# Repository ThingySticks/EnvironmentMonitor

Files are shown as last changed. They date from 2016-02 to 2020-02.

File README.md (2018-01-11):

# Environment Monitor ThingySticks

Particle Photon or Electron based board to measure Humidity, Temperature, Light level and pressure.

* Compaible with Particle Power Shield to allow completly wireless monitoring.
* Compaible with Particle Asset Sheild to allow location information to be included with sensor data.
* Works with Photon or Electron.

## V2:

* Temperature, Humidity (HTU21D)
* Pressure (BMP180)
* Light (TEMT6000)
* Uses a Particle Photon or Electron
* Can piggyback onto Particle Asset Tracker and other ThingySticks prototype PCBs

Available on Tindie: https://www.tindie.com/products/ThingySticks/environment-sensor-for-the-photon-or-electron/

## V3:

Uses a BME680 - These are currently very hard (i.e. impossible) to get hold of. They were expected to be sold over a year ago, hence V3 of the monitor is on-hold.

## V4:

* Total Volatile Organic Compounds (TVOC) (CCS811)
* Equivelant CO2 (CCS811)
* Temperature, Humidity and Pressure (BME280)
* Light (TEMT6000)
* Uses a Particle Photon or Electron
* Can piggyback onto Particle Asset Tracker and other ThingySticks prototype PCBs

Available on Tindie: https://www.tindie.com/products/ThingySticks/air-quality-sensor-bme280ccs811-thingystick/

Build Files
-----------

Files used by the CI server to automate Eagle as part of a build process.

Clean.bat - As it says, pre build clean.
Build.bat - The build tasks (Generate images of the schematic, PCB top, bottom, all and measurements layers).
Distribute.bat - Copy the images to the appropriate places (S3....)

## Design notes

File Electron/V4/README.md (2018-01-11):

# Air Quality Thingy Stick

An air quality ThingyStick for the Particle Photon and Electron.

## Measures:

* Total Volatile Organic Compounds (TVOC) (CCS811)
* Equivelant CO2 (CCS811)
* Temperature, Humidity and Pressure (BME280)
* Light (TEMT6000)

## Buy

Available on Tindie: https://www.tindie.com/products/ThingySticks/air-quality-sensor-bme280ccs811-thingystick/

## Docs

http://thingysticks.com/Environment/V4/

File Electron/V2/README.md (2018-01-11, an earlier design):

# Environment Sensor ThingyStick

An environment sensor ThingyStick for the Particle Photon and Electron.

## Measures:

* Temperature, Humidity (HTU21D)
* Pressure (BMP180)
* Light (TEMT6000)

## Buy

Available on Tindie: https://www.tindie.com/products/ThingySticks/environment-sensor-for-the-photon-or-electron/

## Docs

http://thingysticks.com/Environment/V2/

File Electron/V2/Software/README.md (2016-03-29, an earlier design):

When using the build.particle.io platform you will need to manually add the HTU21D and PowerShield libraries (and remove the duplicated #includes at the head of the file.

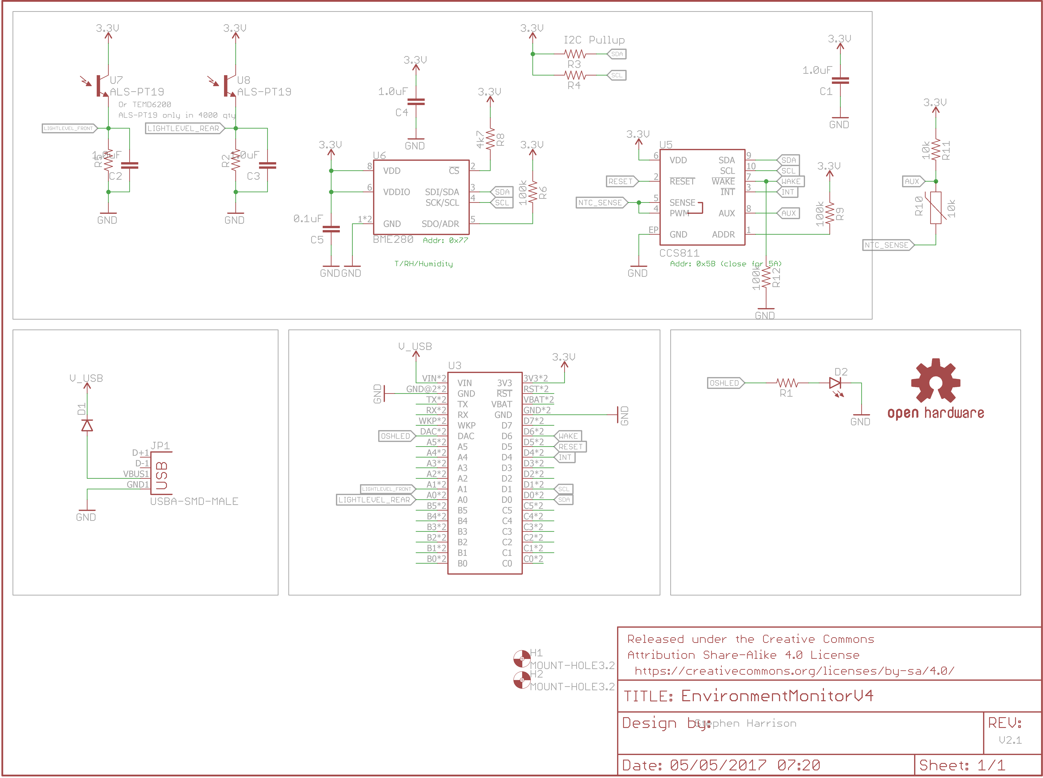
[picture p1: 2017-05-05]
Electron/V4/Images/Schematic.png

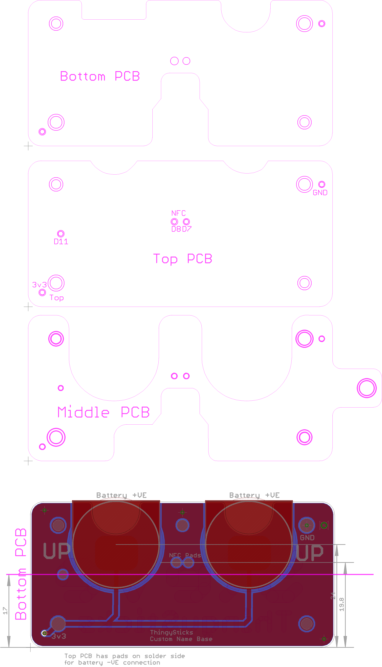
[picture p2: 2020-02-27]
ArduinoNano33/V10/BottomCustom/Images/V10.1/PcbAllLayersDesign.png

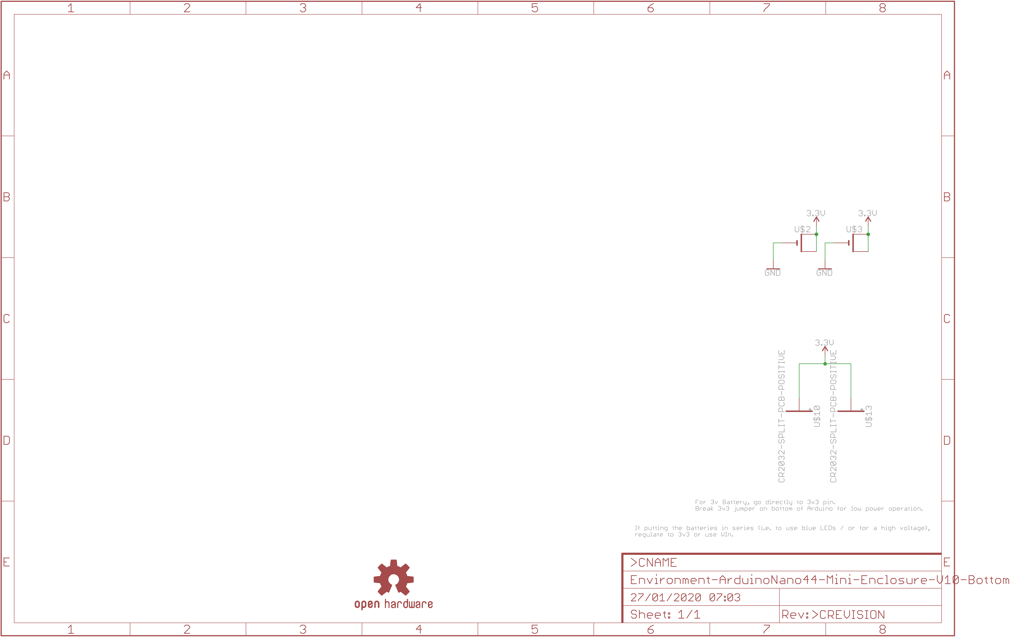
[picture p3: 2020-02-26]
ArduinoNano33/V10/BottomBasic/Images/V10/Schematic.png

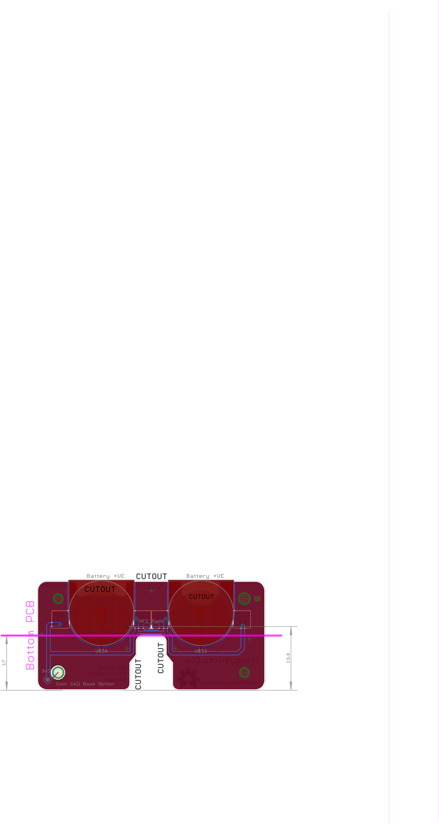
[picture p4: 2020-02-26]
ArduinoNano33/V10/BottomBasic/Images/V10/PcbAllLayersDesign.png

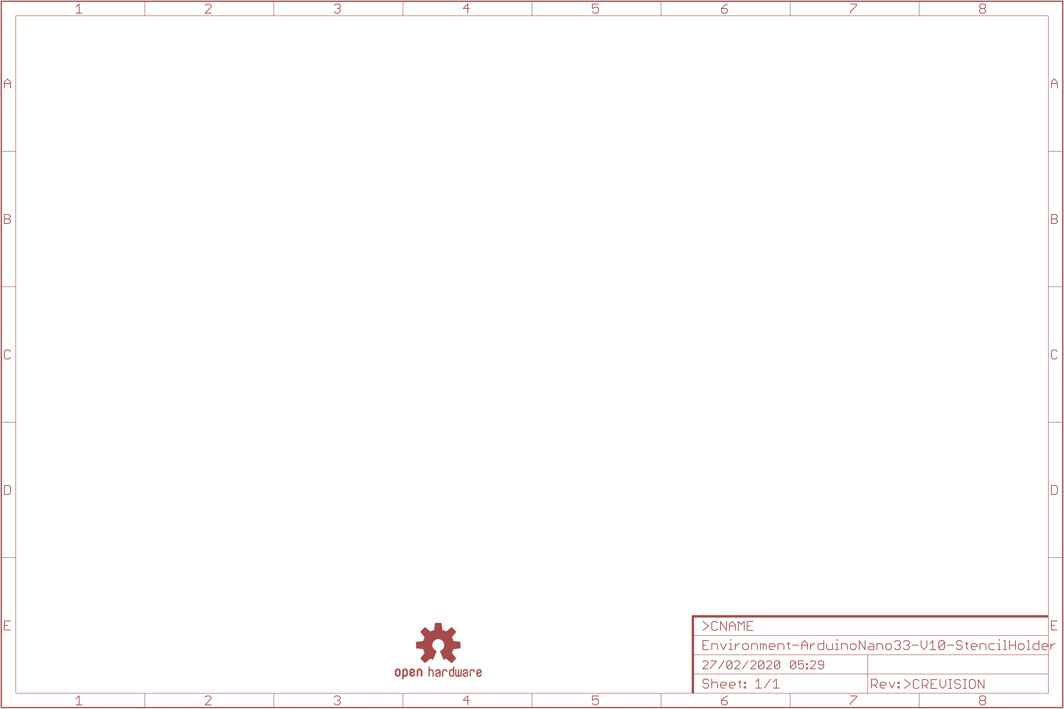
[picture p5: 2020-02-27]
ArduinoNano33/V10/StencilHolder/Images/Schematic.png

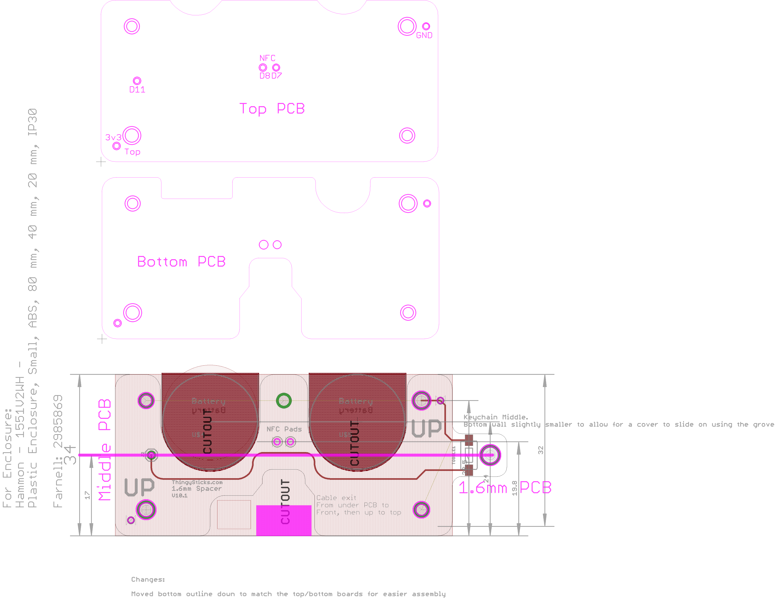
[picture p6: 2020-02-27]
ArduinoNano33/V10/MiddleWithRing/Images/V10.1/PcbAllLayersDesign.png

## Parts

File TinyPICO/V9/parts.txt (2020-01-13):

Partlist

Exported from Environment-TinyPICO-Mini-Enclosure-V9.brd at 12/01/2020 23:53

EAGLE Version 7.4.0 Copyright (c) 1988-2015 CadSoft

Assembly variant: 

Part     Value                      Package                    Library            Position (inch)       Orientation

BT2                                 BATTCON_12MM_PTH           ThingySticks       (2.06161417 0.33622047) R180
BT3                                 BATTCON_12MM_PTH           ThingySticks       (2.04911417 0.99517717) R0
C1       0.1uF                      0805                       ThingySticks       (0.425 0.1375)        R270
C2       1.0uF                      0805                       ThingySticks       (0.5125 0.1375)       R270
D1       Red                        LED-1206                   ThingySticks       (1.0625 1.2625)       R0
D2       Yellow                     LED-1206                   ThingySticks       (0.7875 1.2625)       R0
D3       Green                      LED-1206                   ThingySticks       (0.5125 1.2625)       R0
IC1      BME680                     BME680                     ThingySticks       (0.68897638 0.13061024) R90
J1                                  JST-2-SMD                  ThingySticks       (2.51968504 0.66929134) R90
JP1      JUMPER-SMT_2_NC_PASTE_SILK SMT-JUMPER_2_NC_PASTE_SILK SparkFun-Jumpers   (0.46318898 0.75875984) MR270
JP2      USB-NEW-MICROB             USB-MICROB                 Tinamous           (1.3976378 0.11811024) R0
R1       10k                        0805                       SparkFun-Resistors (0.85 0.2125)         R90
R2       4k7                        0805                       SparkFun-Resistors (1 0.55)              R90
R3       4k7                        0805                       SparkFun-Resistors (0.9 0.55)            R90
R4       1k5                        0805                       SparkFun-Resistors (0.4875 1.1625)       R0
R5       1k5                        0805                       SparkFun-Resistors (0.7625 1.1625)       R0
R6       1k5                        0805                       SparkFun-Resistors (0.9625 1.1625)       R180
U$2      TINY_PICO                  TINY_PICO                  ThingySticks       (0 1.0125)            R270

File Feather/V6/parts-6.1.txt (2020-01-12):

Partlist

Exported from EnvironmentMonitorV6.1.brd at 15/02/2019 21:37

EAGLE Version 7.4.0 Copyright (c) 1988-2015 CadSoft

Assembly variant: 

Part     Value                          Package                     Library                Position (mm)         Orientation

BT2                                     BATTERY_CR2-HOLDER-NO-HOLES ThingySticks           (15.6464 39.1668)     MR270
C1       1.0uF                          0805-CAP                    SparkFun-Capacitors    (49.6225 14.2425)     R180
C2       0.1uF                          0805-CAP                    SparkFun-Capacitors    (49.39 5.4)           R0
C3       1.0uF                          0805-CAP                    SparkFun-Capacitors    (46.0788 6.2206)      R270
C4       0.1uF                          0805-CAP                    SparkFun-Capacitors    (42.575 5.75)         R0
C5       1.0uF                          0805-CAP                    SparkFun-Capacitors    (64.2275 12.3375)     R180
C6       1.0uF                          0805-CAP                    SparkFun-Capacitors    (29.685 56.6175)      R180
C7       0.1uF                          0805-CAP                    SparkFun-Capacitors    (30.32 53.76)         R180
C8       0.1uF                          0805-CAP                    SparkFun-Capacitors    (15.875 62.865)       R270
C9       0.1uF                          0805-CAP                    SparkFun-Capacitors    (12.065 51.435)       R90
C10      10uF                           0805-CAP                    SparkFun-Capacitors    (13.335 62.865)       R90
C11      1.0uF                          0805-CAP                    SparkFun-Capacitors    (21.3 16.93)          R270
C12      2.2uF                          0805-CAP                    SparkFun-Capacitors    (18.7 17.03)          R270
C13      10uF                           0805-CAP                    SparkFun-Capacitors    (14.7 19.665)         R0
C14      0.1uF                          0805-CAP                    SparkFun-Capacitors    (14.7 16.465)         R0
C15      0.1uF                          0805-CAP                    SparkFun-Capacitors    (53.9496 23.4696)     R270
C16      10uF                           0805-CAP                    SparkFun-Capacitors    (51.997 23.5188)      R270
C17      0.1uF                          0805-CAP                    SparkFun-Capacitors    (10.16 60.96)         R180
C19      68uF                           EIA3528                     SparkFun-Capacitors    (8.5725 19.05)        R90
D1       IR                             LED-1206                    SparkFun-LED           (0.889 9.3726)        R270
D2                                      LED-1206-BOTTOM             SparkFun-LED           (43.815 66.04)        R180
D3       IR                             LED-1206                    SparkFun-LED           (3.77 9.365)          R270
D4                                      LED-1206                    ThingySticks           (33.9806 34.0044)     R180
D7       3A/10V/280mV                   SOD-323                     SparkFun-DiscreteSemi  (11.3538 36.9316)     R180
F1       6V/0.75A                       1206                        SparkFun-Fuses         (36.2712 36.8935)     R180
IC1      BME680                         BME680                      ThingySticks           (49.885 9.23)         R180
IC2      TCS3472                        FN-6                        TCS3472                (42.665 9.335)        R180
IC3      CCS811                         LGA10                       ThingySticks           (60 9.3)              R90
IC4                                     SPW2430HR5H-B               microbuilder           (13.97 58.42)         R0
IC5      FEATHERWINGPADS_AND_PLACE_ONLY FEATHERWIND_PADS_AND_PLACE  ThingySticks           (18.415 62.23)        MR180
J1                                      JST-2-SMD                   ThingySticks           (22.03 34.2225)       MR90
JP1      Charge Enable                  SMT-JUMPER_2_NC_PASTE_SILK  SparkFun-Jumpers       (11.3538 34.2646)     R180
JP2      Analog                         JST-4-PH-GROVE              ThingySticks           (26.035 67.945)       MR0
JP3      Serial                         JST-4-PH-GROVE              ThingySticks           (57.815 67.99)        MR0
JP6      I2C                            JST-4-PH-GROVE              ThingySticks           (60.325 33.02)        MR0
Q1       IRFML8244TRPBF                 SOT23-3                     SparkFun-DiscreteSemi  (4.3 4.715)           R0
Q2       4.3A/20V/54m?                  SOT23-3                     SparkFun-DiscreteSemi  (14.605 23.8125)      R270
R1       1k5                            0805                        SparkFun-Resistors     (50.295 66.03)        R0
R2       1K                             0805                        SparkFun-Resistors     (10.0584 63.8556)     R0
R3       4k7                            0805                        SparkFun-Resistors     (29.7365 20.0624)     R180
R4       4k7                            0805                        SparkFun-Resistors     (27.7553 17.9034)     R180
R5       10k                            0805                        SparkFun-Resistors     (47.625 48.895)       R90
R6       1M                             0805                        SparkFun-Resistors     (0.635 58.42)         R90
R7       10k                            0805                        SparkFun-Resistors     (8.89 51.435)         R90
R8       10k                            0805                        SparkFun-Resistors     (57.7342 29.9974)     R180
R9       10k                            0805                        SparkFun-Resistors     (57.785 46.99)        R90
R10      10k                            0805                        SparkFun-Resistors     (55.245 48.895)       R90
R11      4k7                            0805                        SparkFun-Resistors     (56.56 4.22)          R180
R12      10k                            0805                        SparkFun-Resistors     (5.715 51.435)        R270
R13      100R                           0805                        SparkFun-Resistors     (10.795 29.21)        R0
R14      20R                            0805                        SparkFun-Resistors     (21.3 22.1)           R90
R15      100R                           0805                        SparkFun-Resistors     (0.87 15.065)         R90
R16      1K                             0805                        SparkFun-Resistors     (39.5478 34.0298)     R0
R17      100R                           0805                        SparkFun-Resistors     (3.77 15.065)         R90
R18      10R                            0805                        SparkFun-Resistors     (-0.83 4.595)         R90
R19      1M                             0805                        SparkFun-Resistors     (4.2648 1.3122)       R0
R20      10k                            0805                        SparkFun-Resistors     (5.715 47.625)        R270
R21      10k                            0805                        SparkFun-Resistors     (52.705 45.085)       R90
R22      10k                            0805                        SparkFun-Resistors     (50.165 45.085)       R90
R23      1M                             0805                        SparkFun-Resistors     (14.605 29.21)        R180
U1       GRIDEYE                        GRIDEYE-AMG88               SparkFun-Sensors       (20 9.4126)           R0
U2       LMV358                         SO08                        SparkFun-IC-Amplifiers (6.35 57.15)          R270
U3       LIS3DH                         LGA-16-3X3                  SparkFun-Sensors       (58.42 25.4)          R180

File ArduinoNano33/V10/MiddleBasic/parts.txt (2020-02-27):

Partlist

Exported from Environment-ArduinoNano33-V10.1-MiddleBasic.brd at 27/02/2020 23:39

EAGLE Version 7.4.0 Copyright (c) 1988-2015 CadSoft

Assembly variant: 

Part     Value          Package  Library             Position (mm)         Orientation

J2                      1X01     SparkFun-Connectors (7.6 17)              R0

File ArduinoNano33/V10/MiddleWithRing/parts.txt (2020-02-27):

Partlist

Exported from Environment-ArduinoNano-V10.1-Middle-KeyChain.brd at 27/02/2020 23:31

EAGLE Version 7.4.0 Copyright (c) 1988-2015 CadSoft

Assembly variant: 

Part     Value                               Package                      Library             Position (mm)         Orientation

J2                                           1X01                         SparkFun-Connectors (7.6 17)              R0
TOGGLE1  MOMENTARY-SWITCH-SPST-SMD-6.0X3.5MM TACTILE_SWITCH_SMD_6.0X3.5MM ThingySticks        (74.5 17)             R90

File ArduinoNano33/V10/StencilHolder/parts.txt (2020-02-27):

Partlist

Exported from Environment-ArduinoNano33-V10-StencilHolder.brd at 27/02/2020 23:18

EAGLE Version 7.4.0 Copyright (c) 1988-2015 CadSoft

Assembly variant: 

Part     Value          Package  Library  Position (mm)         Orientation

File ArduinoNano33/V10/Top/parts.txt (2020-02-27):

Partlist

Exported from Environment-ArduinoNano33-V10.1-Top.brd at 27/02/2020 07:29

EAGLE Version 7.4.0 Copyright (c) 1988-2015 CadSoft

Assembly variant: 

Part     Value                                             Package                        Library                        Position (mm)         Orientation

C1       0.1uF                                             0805                           ThingySticks                   (10.795 3.4925)       R270
C2       1.0uF                                             0805                           ThingySticks                   (13.0175 3.4925)      R270
D1       Red                                               LED-1206                       ThingySticks                   (66.5 32.5)           R0
D2       Green                                             LED-1206                       ThingySticks                   (5 32.5)              R180
D3       Yellow                                            LED-1206                       ThingySticks                   (35.5 32.5)           R0
D4       Blue                                              LED-1206                       ThingySticks                   (47.5 20)             R270
D5       Blue                                              LED-1206                       ThingySticks                   (47.5 14)             R90
D6       Blue                                              LED-1206                       ThingySticks                   (50.5 11)             R0
D7       Blue                                              LED-1206                       ThingySticks                   (53.5 14)             R90
D8       Blue                                              LED-1206                       ThingySticks                   (53.5 20)             R90
D9       Blue                                              LED-1206                       ThingySticks                   (50.5 23)             R0
D10      Blue                                              LED-1206                       ThingySticks                   (50.5 17)             R180
D11      Blue                                              LED-1206                       ThingySticks                   (67.8 9.3)            R315
D13      Blue                                              LED-1206                       ThingySticks                   (60 20)               R90
D14      Blue                                              LED-1206                       ThingySticks                   (60 14)               R270
D15      Blue                                              LED-1206                       ThingySticks                   (63 11)               R0
D16      Blue                                              LED-1206                       ThingySticks                   (66 14)               R90
D17      Blue                                              LED-1206                       ThingySticks                   (66 20)               R270
D18      Blue                                              LED-1206                       ThingySticks                   (63 23)               R180
D19      Blue                                              LED-1206                       ThingySticks                   (63 17)               R0
D20      Green                                             LED-1206                       ThingySticks                   (50.5 2)              R0
D21      Green                                             LED-1206                       ThingySticks                   (63 2)                R180
D22      Blue                                              LED-1206                       ThingySticks                   (57 11.5)             R270
D23      Green                                             LED-1206                       ThingySticks                   (57 2)                R180
IC1      BME680                                            BME680                         ThingySticks                   (17.5 3.3175)         R90
J1                                                         1X01                           SparkFun-Connectors            (36.9 19.8)           R270
J3                                                         1X01                           SparkFun-Connectors            (7.6 17)              R0
J4       QUIC                                              JST04_1MM_RA                   SparkFun-Connectors-2020-01-17 (24.5 5)              MR0
J6                                                         1X01                           SparkFun-Connectors            (34.1 19.8)           R270
JP1      USB-NEW-MICROB                                    USB-MICROB                     Tinamous                       (35.4 3)              MR0
Q1       5.8A/30V/35m?                                     SOT23-3                        SparkFun-DiscreteSemi          (50.5 7)              R0
Q2       5.8A/30V/35m?                                     SOT23-3                        SparkFun-DiscreteSemi          (59.5 7)              R0
R1       10k                                               0805                           SparkFun-Resistors             (21.59 4.7975)        R90
R2       1k5                                               0805                           SparkFun-Resistors             (2 5.5)               R270
R3       1k5                                               0805                           SparkFun-Resistors             (35 28.8175)          R180
R4       1k5                                               0805                           SparkFun-Resistors             (31 33)               R180
R5       1k5                                               0805                           SparkFun-Resistors             (10.5 32)             R270
R6       200k                                              0805                           SparkFun-Resistors             (27.25 2.25)          R90
R7       100k                                              0805                           SparkFun-Resistors             (29.9 2.95)           R0
R9       1k5                                               0805                           SparkFun-Resistors             (54.5 9)              R90
R10      1k5                                               0805                           SparkFun-Resistors             (47 9)                R90
R11      1k5                                               0805                           SparkFun-Resistors             (2 29)                R90
R12      1k5                                               0805                           SparkFun-Resistors             (28 29)               R270
R13      1k5                                               0805                           SparkFun-Resistors             (30.5 29)             R270
R14      1k5                                               0805                           SparkFun-Resistors             (62 32.5)             R180
U$1      ARDUINO_33_NANOARDUINO_NANO_33_BLE_SENSE_SMD_WIDE ARDUINO_NANO_33_SMD_WIDER_PADS ThingySticks                   (1.25 8.305)          R90
U$6                                                        CR2032-SMD                     ThingySticks                   (20 24)               MR0
U$8      CR2032-SPLIT-PCBCR2032-NEGATIVE                   CR2032-SMD-NEGATIVE-TERMINAL   ThingySticks                   (20 24)               MR0
U$9      CR2032-SPLIT-PCBCR2032-NEGATIVE                   CR2032-SMD-NEGATIVE-TERMINAL   ThingySticks                   (51 24)               MR0

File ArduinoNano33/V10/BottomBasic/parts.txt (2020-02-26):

Partlist

Exported from Environment-ArduinoNano44-Mini-Enclosure-V10-Bottom.brd at 26/02/2020 16:30

EAGLE Version 7.4.0 Copyright (c) 1988-2015 CadSoft

Assembly variant: 

Part     Value                     Package                      Library      Position (mm)         Orientation

U$2                                CR2032-SMD                   ThingySticks (20 59)               MR0
U$3                                CR2032-SMD                   ThingySticks (51 59)               MR0
U$10     CR2032-SPLIT-PCB-POSITIVE CR2032-SMD-POSITIVE-TERMINAL ThingySticks (20 61)               MR0
U$13     CR2032-SPLIT-PCB-POSITIVE CR2032-SMD-POSITIVE-TERMINAL ThingySticks (51 61)               MR0

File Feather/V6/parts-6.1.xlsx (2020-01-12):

Partl | ist
Expor | ted | from Envir | onmentMonitorV6.1.brd at 15/02/2019 21:37
EAGLE | Ver | sion 7.4.0 | Copyright (c) 1988-2015 CadSoft
 |  |  |  |  |  |  |  |  |  | Number to make | 20
Assem | bly | variant: |  |  |  |  |  |  |  | Cost of parts | 746.82
 |  |  |  |  |  |  |  | Cost / Unit (@25) | QTY | Total
Part |  | Value | Package | Library | Position (mm) | Orientation |  | 68.731 | 56 | 37.341
C1 |  | 1.0uF | 0805-CAP | SparkFun-Capacitors | (49.6225 14.2425) | R180 | MC0805F105Z160CT | 0.114 | 1 | 0.114
C2 |  | 0.1uF | 0805-CAP | SparkFun-Capacitors | (49.39 5.4) | R0 | MC0805B104K101CT | 0.0327 | 1 | 0.0327
C3 |  | 1.0uF | 0805-CAP | SparkFun-Capacitors | (46.0788 6.2206) | R270 | MC0805F105Z160CT | 0.114 | 1 | 0.114
C4 |  | 0.1uF | 0805-CAP | SparkFun-Capacitors | (42.575 5.75) | R0 | MC0805B104K101CT | 0.0327 | 1 | 0.0327
C5 |  | 1.0uF | 0805-CAP | SparkFun-Capacitors | (64.2275 12.3375) | R180 | MC0805F105Z160CT | 0.114 | 1 | 0.114
C6 |  | 1.0uF | 0805-CAP | SparkFun-Capacitors | (29.685 56.6175) | R180 | MC0805F105Z160CT | 0.114 | 1 | 0.114
C7 |  | 0.1uF | 0805-CAP | SparkFun-Capacitors | (30.32 53.76) | R180 | MC0805B104K101CT | 0.0327 | 1 | 0.0327
C8 |  | 0.1uF | 0805-CAP | SparkFun-Capacitors | (15.875 62.865) | R270 | MC0805B104K101CT | 0.0327 | 1 | 0.0327
C9 |  | 0.1uF | 0805-CAP | SparkFun-Capacitors | (12.065 51.435) | R90 | MC0805B104K101CT | 0.0327 | 1 | 0.0327
C10 |  | 10uF | 0805-CAP | SparkFun-Capacitors | (13.335 62.865) | R90 | MC0805F105Z160CT | 0.0631 | 1 | 0.0631
C11 |  | 1.0uF | 0805-CAP | SparkFun-Capacitors | (21.3 16.93) | R270 | MC0805F105Z160CT | 0.114 | 1 | 0.114
C12 |  | 2.2uF | 0805-CAP | SparkFun-Capacitors | (18.7 17.03) | R270 | MC0805B225K250CT | 0.226 | 1 | 0.226
C13 |  | 10uF | 0805-CAP | SparkFun-Capacitors | (14.7 19.665) | R0 | MC0805F105Z160CT | 0.0631 | 1 | 0.0631
C14 |  | 0.1uF | 0805-CAP | SparkFun-Capacitors | (14.7 16.465) | R0 | MC0805B104K101CT | 0.0327 | 1 | 0.0327
C15 |  | 0.1uF | 0805-CAP | SparkFun-Capacitors | (53.9496 23.4696) | R270 | MC0805B104K101CT | 0.0327 | 1 | 0.0327
C16 |  | 10uF | 0805-CAP | SparkFun-Capacitors | (51.997 23.5188) | R270 | MC0805F105Z160CT | 0.0631 | 1 | 0.0631
C17 |  | 0.1uF | 0805-CAP | SparkFun-Capacitors | (10.16 60.96) | R180 | MC0805B104K101CT | 0.0327 | 1 | 0.0327
C19 |  | 68uF | EIA3528 | SparkFun-Capacitors | (8.5725 19.05) | R90 | T499B336K006ATE3K0 | 0.741 | 1 | 0.741
D1 |  | IR | LED-1206 | SparkFun-LED | (0.889 9.3726) | R270 | OIS 330 770 | 1.24 | 1 | 1.24
D4 |  | Reverse LED | LED-1206 | ThingySticks | (33.9806 34.0044) | R180 | KPTL-3216QBC-D-01 | 0.2 | 1 | 0.2 |  | 0.247 | 25x 0.20 |  |  | 100x 0.184
F1 |  | 6V/0.75A | 1206 | SparkFun-Fuses | (36.2712 36.8935) | R180 | 1206L075THYR (https://uk.farnell.com/littelfuse/1206l075thyr/polyfuse-ptc-1206-0-75a/dp/1822204?st=1206%20LITTLE%20FUSE) | 0.3 | 1 | 0.3
IC1 |  | BME680 | BME680 | ThingySticks | (49.885 9.23) | R180 | BME680 | 8.22 | 1 | 8.22 |  | 1x 9.84 | 10x 8.22 | 25x 7.62 | 50x 7.41 | 100x 6.38 | 250x 6.17 | 2500x 4.94
IC2 |  | TCS3472 | FN-6 | TCS3472 | (42.665 9.335) | R180 | TCS34725FN | 1.96 | 1 | 1.96 |  | 1x 2.44 | 10x2.18 | 25x 1.96 | 50x 1.87 | 100x 1.78 | 250x 1.62 | 2000x 1.18 | 3500x 1.18
IC3 |  | CCS811 | LGA10 | ThingySticks | (60 9.3) | R90 | CCS811B-JOPD500 | 6.89 | 1 | 6.89 |  | 1x 8.62 | 10x 7.76 | 25x 6.89 | 6.37 | 5.51 | 5.16 | 1000x 4.39
IC4 |  |  | SPW2430HR5H-B | microbuilder | (13.97 58.42) | R0 | SPW2430HR5H-B | 0.441 | 1 | 0.441 |  | 0.656 | 0.52 | 0.441 | 0.401 | 0.377 | 0.352 | 0.241
J1 |  |  | JST-2-SMD | ThingySticks | (22.03 34.2225) | MR90 |  |  | 1 | 0
Q1 |  | IRFML8244T | RPBF SOT23-3 | SparkFun-DiscreteSem | i (4.3 4.715) | R0 | IRFML8244TRPBF | 0.212 | 1 | 0.212
Q2 |  | P-Channel | 4m? SOT23-3 | SparkFun-DiscreteSem | i (14.605 23.8125) | R270 |  | 0.212 | 1 | 0.212
R1 |  | 1k5 | 805 | SparkFun-Resistors | (50.295 66.03) | R0 | MCWR08X1501FTL | 0.0016 | 1 | 0.0016
R2 |  | 1K | 805 | SparkFun-Resistors | (10.0584 63.8556) | R0 | MCWR08X1001FTL | 0.0081 | 1 | 0.0081
R3 |  | 4k7 | 805 | SparkFun-Resistors | (29.7365 20.0624) | R180 | MCWR08X4701FTL | 0.0081 | 1 | 0.0081
R4 |  | 4k7 | 805 | SparkFun-Resistors | (27.7553 17.9034) | R180 | MCWR08X4701FTL | 0.0081 | 1 | 0.0081
R5 |  | 10k | 805 | SparkFun-Resistors | (47.625 48.895) | R90 | MCWR08X1002FTL | 0.0086 | 1 | 0.0086
R6 |  | 1M | 805 | SparkFun-Resistors | (0.635 58.42) | R90 | MCWR08X1004FTL | 0.0086 | 1 | 0.0086
R7 |  | 10k | 805 | SparkFun-Resistors | (8.89 51.435) | R90 | MCWR08X1002FTL | 0.0086 | 1 | 0.0086
R8 |  | 10k | 805 | SparkFun-Resistors | (57.7342 29.9974) | R180 | MCWR08X1002FTL | 0.0086 | 1 | 0.0086
R9 |  | 10k | 805 | SparkFun-Resistors | (57.785 46.99) | R90 | MCWR08X1002FTL | 0.0086 | 1 | 0.0086
R10 |  | 10k | 805 | SparkFun-Resistors | (55.245 48.895) | R90 | MCWR08X1002FTL | 0.0086 | 1 | 0.0086
R11 |  | 4k7 | 805 | SparkFun-Resistors | (56.56 4.22) | R180 | MCWR08X4701FTL | 0.0081 | 1 | 0.0081
R12 |  | 10k | 805 | SparkFun-Resistors | (5.715 51.435) | R270 | MCWR08X1002FTL | 0.0086 | 1 | 0.0086
R13 |  | 100R | 805 | SparkFun-Resistors | (10.795 29.21) | R0 | MCWR08X1000FTL | 0.0086 | 1 | 0.0086
R14 |  | 20R | 805 | SparkFun-Resistors | (21.3 22.1) | R90 | MCWR08X20R0FTL | 0.0084 | 1 | 0.0084
R15 |  | 100R | 805 | SparkFun-Resistors | (0.87 15.065) | R90 | MCWR08X1000FTL | 0.0086 | 1 | 0.0086
R16 |  | 1K | 805 | SparkFun-Resistors | (39.5478 34.0298) | R0 | MCWR08X1001FTL | 0.0081 | 1 | 0.0081
R17 |  | 100R | 805 | SparkFun-Resistors | (3.77 15.065) | R90 | MCWR08X1000FTL | 0.0086 | 1 | 0.0086
R18 |  | 10R | 805 | SparkFun-Resistors | (-0.83 4.595) | R90 | MCWR08X10R0FTL | 0.0016 | 1 | 0.0016
R19 |  | 1M | 805 | SparkFun-Resistors | (4.2648 1.3122) | R0 | MCWR08X1004FTL | 0.0086 | 1 | 0.0086
R20 |  | 10k | 805 | SparkFun-Resistors | (5.715 47.625) | R270 | MCWR08X1002FTL | 0.0086 | 1 | 0.0086
R21 |  | 10k | 805 | SparkFun-Resistors | (52.705 45.085) | R90 | MCWR08X1002FTL | 0.0086 | 1 | 0.0086
R22 |  | 10k | 805 | SparkFun-Resistors | (50.165 45.085) | R90 | MCWR08X1002FTL | 0.0086 | 1 | 0.0086
R23 |  | 1M | 805 | SparkFun-Resistors | (14.605 29.21) | R180 | MCWR08X1004FTL | 0.0086 | 1 | 0.0086
U1 |  | GRIDEYE | GRIDEYE-AMG88 | SparkFun-Sensors | (20 9.4126) | R0 | AMG8833 | 16.39 | 0 | 0 |  | 16.91 | 10x 16.39 | 50x 14.49 | 100x 13.32
U2 |  | LMV358 | SO08 | SparkFun-IC-Amplifie | rs (6.35 57.15) | R270 | LMV358ID | 0.486 | 1 | 0.486 |  | 0.556 | 50x 0.486 | 100x 0.313 | 250x 0.292 | 500x 2.72
U3 |  | LIS3DH | LGA-16-3X3 | SparkFun-Sensors | (58.42 25.4) | R180 | LIS3DHHTR | 0.961 | 1 | 0.961 |  | 1.12 | 10x 0.961 | 100x 0.738 | 500x 0.654
 |  | PCB Cost |  |  |  |  |  | 2 | 1 | 2
 |  | Assembly Cost |  |  |  |  |  | 9.35 | 1 | 9.35 |  | 1-49 $12.2 | 50-200 $5.4 | 200-500 $2.0
 |  | Enclosure |  |  |  |  |  | 2.7 | 1 | 2.7 |  | 2.76 | 25x 2.70 | 50x 2.65 | 250x 2.59
 |  | Xenon |  |  |  |  |  | 15 | 0 | 0
 |  |  |  |  |  |  |  |  |  |  |  | 2.65 | 250 | 662.5

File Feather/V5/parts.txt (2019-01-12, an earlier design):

Partlist exported from S:/github/ThingySticks/EnvironmentMonitor/Feather/V5/PCB/EnvironmentMonitorV5.sch at 12/01/2019 20:36

Part   Value             Device                   Package          Description                                                                                                                           CPC     PROD_ID     SEEEDSTUDIO VALUE         
C1     1.0uF             1.0UF-25V-+80/-20(0805)" 0805-CAP         CAP-11625                                                                                                                                     CAP-11625               1.0uF         
C2     0.1uF             1.0UF-25V-+80/-20(0805)" 0805-CAP         CAP-11625                                                                                                                                     CAP-11625               1.0uF         
C3     1.0uF             1.0UF-25V-+80/-20(0805)" 0805-CAP         CAP-11625                                                                                                                                     CAP-11625               1.0uF         
C4     0.1uF             1.0UF-25V-+80/-20(0805)" 0805-CAP         CAP-11625                                                                                                                                     CAP-11625               1.0uF         
D2                       LED1206-BOTTOM           LED-1206-BOTTOM  LEDs                                                                                                                                                                                
FRAME1 FRAME-LETTER      FRAME-LETTER             CREATIVE_COMMONS Schematic Frame                                                                                                                                                                     
H1     MOUNT-HOLE2.8     MOUNT-HOLE2.8            2,8              MOUNTING HOLE with drill center marker                                                                                                                                              
H2     MOUNT-HOLE2.8     MOUNT-HOLE2.8            2,8              MOUNTING HOLE with drill center marker                                                                                                                                              
H3     MOUNT-HOLE2.8     MOUNT-HOLE2.8            2,8              MOUNTING HOLE with drill center marker                                                                                                                                              
H4     MOUNT-HOLE2.8     MOUNT-HOLE2.8            2,8              MOUNTING HOLE with drill center marker                                                                                                                                              
IC1    BME680            BME680                   BME680           BME680 integrates for the first time individual high linearity and high accuracy sensors for gas, pressure, humidity and temperature.                                               
IC2    TCS3472           TCS3472                  FN-6                                                                                                                                                                                                 
JP1    A1-2              M04JST-PTH-VERT          JST-4-PTH-VERT   Header 4                                                                                                                              MK00368             110990030                 
JP2    A3-4              M04JST-PTH-VERT          JST-4-PTH-VERT   Header 4                                                                                                                                                                            
JP3    Serial            M04JST-PTH-VERT          JST-4-PTH-VERT   Header 4                                                                                                                                                                            
JP4    D7-8              M04JST-PTH-VERT          JST-4-PTH-VERT   Header 4                                                                                                                                                                            
JP5    I2C1 - D2-3       M04JST-PTH-VERT          JST-4-PTH-VERT   Header 4                                                                                                                                                                            
JP6    I2C               M04JST-PTH-VERT          JST-4-PTH-VERT   Header 4                                                                                                                                                                            
JP7    Ext. Power (5v)   M02POLAR_LOCK            MOLEX-1X2_LOCK   Standard 2-pin 0.1" header. Use with                                                                                                                                                
JP9    FAN               M03POLAR                 MOLEX-1X3        Header 3                                                                                                                                                                            
JP10   FAN Power in      M02POLAR_LOCK            MOLEX-1X2_LOCK   Standard 2-pin 0.1" header. Use with                                                                                                                                                
JP11                     M03PTH                   1X03             Header 3                                                                                                                                                                            
LOGO1  OSHW-LOGOM        OSHW-LOGOM               OSHW-LOGO-M      Open Source Hardware Logo                                                                                                                                                           
MS1    FEATHERWING_NODIM FEATHERWING_NODIM        FEATHERWING_DIM                                                                                                                                                                                      
Q1     220mA/50V/3.5O    MOSFET-NCH-BSS138        SOT23-3          N-channel MOSFETs                                                                                                                             TRANS-00830             220mA/50V/3.5O
Q2     4.3A/20V/54mO     MOSFET_PCH-IRLML2244     SOT23-3          P-channel MOSFETs                                                                                                                             TRANS-11153             4.3A/20V/54mO 
R1     310R              RESISTOR0805-RES         0805             Resistor                                                                                                                                                                            
R2     1M                RESISTOR0805-RES         0805             Resistor                                                                                                                                                                            
R3     4k7               RESISTOR0805-RES         0805             Resistor                                                                                                                                                                            
R4     4k7               RESISTOR0805-RES         0805             Resistor                                                                                                                                                                            
R5     10k               RESISTOR0805-RES         0805             Resistor                                                                                                                                                                            
R6     1M                RESISTOR0805-RES         0805             Resistor                                                                                                                                                                            
R7     10R               RESISTOR0805-RES         0805             Resistor

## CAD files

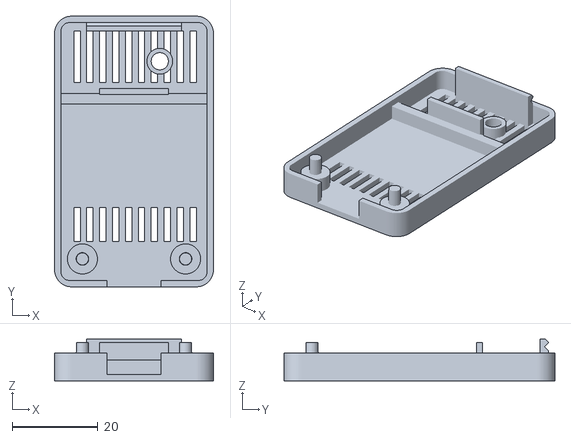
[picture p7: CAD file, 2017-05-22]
Photon/V4.1/Case/PhotonCase.stl
37.0 x 63.0 x 9.75

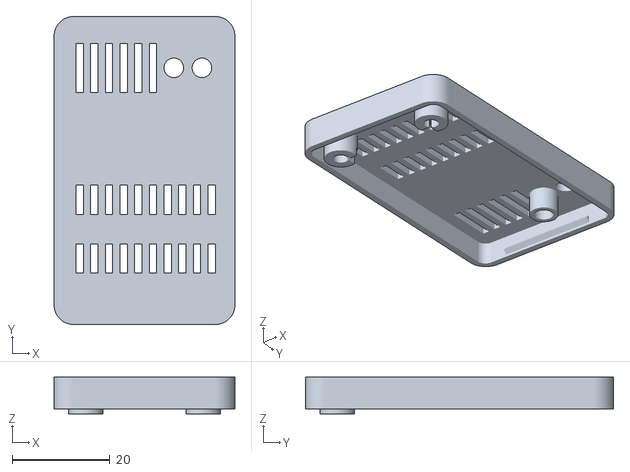
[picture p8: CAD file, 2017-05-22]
Photon/V4.1/Case/PhotonCase-Lid.stl
37.0 x 63.0 x 7.50

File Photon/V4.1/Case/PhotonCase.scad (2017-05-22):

$fn=60;

pcbLength = 55;
pcbWidth = 32;
pcbHeight = 0.8;

pcbXOffset = 2.5;
pcbYOffset = 2.5;
pcbZOffset = 5;

// ==========================================================
// Models
// ==========================================================

module showPcb() {
    roundedCube(pcbWidth, pcbLength, pcbHeight , 4);
    
    // Hole
    translate([4,4,-2]) {
        #cylinder(d=3, h=4);
    }
    
    // Hole
    translate([4+24,4,-2]) {
        cylinder(d=3, h=4);
    }
    
    // Thermal cutout
    translate([7.6,42.1,-2]) {
        cube([pcbWidth-(7.6 * 2),1.6,4]);
    }
    
    // USB
    translate([(pcbWidth-12)/2,-15,-3]) {
        cube([12,15,4.5]);
    }
    
    // Photon
    translate([5.7,5,pcbHeight]) {
        // Height the max of the PCB - USB plug + aerial
        cube([20,37,4]);
    }
    
    // JST for battery
    translate([6,17,-6]) {
        // Height the max of the PCB - USB plug + aerial
        cube([20,10,6]);
    }
    
    // LED
    translate([20,48,-1]) {
        // Height the max of the PCB - USB plug + aerial
        cube([11,5,1]);
    }
    
    translate([28,50,-1]) {
        // Height the max of the PCB - USB plug + aerial
        #cylinder(d=2, h=20);
    }
}

// ==========================================================
// Helpers
// ==========================================================

module roundedCube(width, height, depth, cornerDiameter) {
//cornerDiameter = 5;
cornerRadius = cornerDiameter/2;
    
    translate([cornerDiameter/2,0,0]) {
        cube([width-cornerDiameter, height, depth]);
    }
    
    translate([0,cornerDiameter/2,0]) {
        cube([width, height-cornerDiameter, depth]);
    }
    
    translate([cornerRadius,cornerRadius,0]) {
        cylinder(d=cornerDiameter, h=depth);
    }
    
    translate([width-cornerRadius,cornerRadius,0]) {
        cylinder(d=cornerDiameter, h=depth);
    }
    
    translate([cornerRadius,height-cornerRadius,0]) {
        cylinder(d=cornerDiameter, h=depth);
    }
    
    translate([width-cornerRadius,height-cornerRadius,0]) {
        cylinder(d=cornerDiameter, h=depth);
    }
}

// ==========================================================
// PCB Mounts
// ==========================================================

module pcbMountingPads() {
    translate([pcbXOffset, pcbYOffset,0]) {
        pcbMountingPin(4,4);
        pcbMountingPin(4+24,4);
    }
}

module pcbMountingPad(x,y) {
    translate([x,y,0]) {
        difference() {
            cylinder(d=7, h=pcbZOffset);
            cylinder(d=1, h=4);
        }
    }
}

module pcbMountingPin(x,y) {
    translate([x,y,0]) {
        cylinder(d=7, h=pcbZOffset);
        cylinder(d1=3.1, d2=2.8, h=pcbZOffset+4);
    }
}

// A Support "pad" for the back of the PCB.
// use the slot in the PCB to help stabalise things.
module pcbSupport() {
    translate([pcbXOffset, pcbYOffset,0]) {
        // Add a pad
        // 9mm from pCB edge.
        translate([-pcbXOffset,40,0]) {
            cube([pcbWidth + (pcbXOffset*2),2.5,pcbZOffset-0.1]);
        }
            
        // add a riser
        translate([8,42.25,0]) {
            cube([16,1.4,pcbZOffset+4]);
        }
    }
}

module pcbMountingReceptors() {
    translate([pcbXOffset, pcbYOffset,-1]) {
        pcbMountingReceptor(4,4);
        pcbMountingReceptor(4+24,4);
    }
}

module pcbMountingReceptor(x,y) {
    translate([x,y,0]) {
        difference() {
            cylinder(d=7, h=mainBodyHeight+1);
            cylinder(d=3.2, h=mainBodyHeight+1-2);
        }
    }
}

// ==========================================================

mainBodyHeight = 6.5;
    //mainBodyHeight = 1;

module usbCutout() {
usbWidth  = 12.5;
xPosition = (pcbWidth / 2) - (usbWidth / 2) + pcbXOffset;
    
    // USB plug pretrudes 3.3mm below the PCB 
    translate([xPosition, -0.1,pcbZOffset - 3.5]) {
        // Ensure no top is put onto the USB
       # cube([usbWidth,3,5.5]);
    }
}

module photodiodeTopHole(height) {
    translate([22, 50,0]) {
        difference() {
            union() {
                cylinder(d=6, h=height);
            }
            union() {
                cylinder(d=4, h=height);
            }
        }
    }
}


module body() {   
    
    difference() {
        union() {
            roundedCube(pcbWidth + pcbXOffset * 2, 63, mainBodyHeight, 8) ;
        }
        union() {
            translate([1.5,1.5,1.5]) {
                // 1mm difference between wall nand pcbXOffset
                // double that so it's either side.
                roundedCube(pcbWidth + 2, 60, mainBodyHeight, 4) ;
            }
            
            usbCutout();
            
            // Vent holes for sensors
            translate([pcbXOffset,pcbYOffset,-0.1]) {
                for (i = [2 : 3 : 30]) {
                    translate([i, 45,0]) {
                        #cube([1.5, 12,  2]);
                    }
                }
            }
            
            // Vent holes for Photon heat
            translate([pcbXOffset,pcbYOffset,-0.1]) {
                for (i = [2 : 3 : 30]) {
                    translate([i, 8,0]) {
                        // Shorter to allow for a cutout for the JST
                        #cube([1.5, 8,  2]);
                    }
                }
            }
            
            // Photodiode hole.
            translate([pcbXOffset,pcbYOffset,-0.1]) {
                translate([22, 50,0]) {
                    #cylinder(d=4, h=mainBodyHeight+1);
                }
            }
        }
    }
    
    pcbMountingPads();
    pcbSupport();
    
    translate([pcbXOffset,pcbYOffset,0]) {
        photodiodeTopHole(pcbZOffset-1);
    }
    
    // End catch to get the lid
    translate([7.5,63-3.5,0]) {
        difference() {
            union() {
                cube([pcbWidth-10,2, mainBodyHeight + mainBodyHeight/2]);
            }
            union() {
                translate([0,2.5,mainBodyHeight ]) {
                    rotate([45, 0,0]) {
                        cube([pcbWidth-10,2, 2]);
                    }
                }
                translate([0,2.5,mainBodyHeight+2 ]) {
                    rotate([45, 0,0]) {
                        cube([pcbWidth-10,2, 2]);
                    }
                }
            }
        }
    }
}


module lid() {
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

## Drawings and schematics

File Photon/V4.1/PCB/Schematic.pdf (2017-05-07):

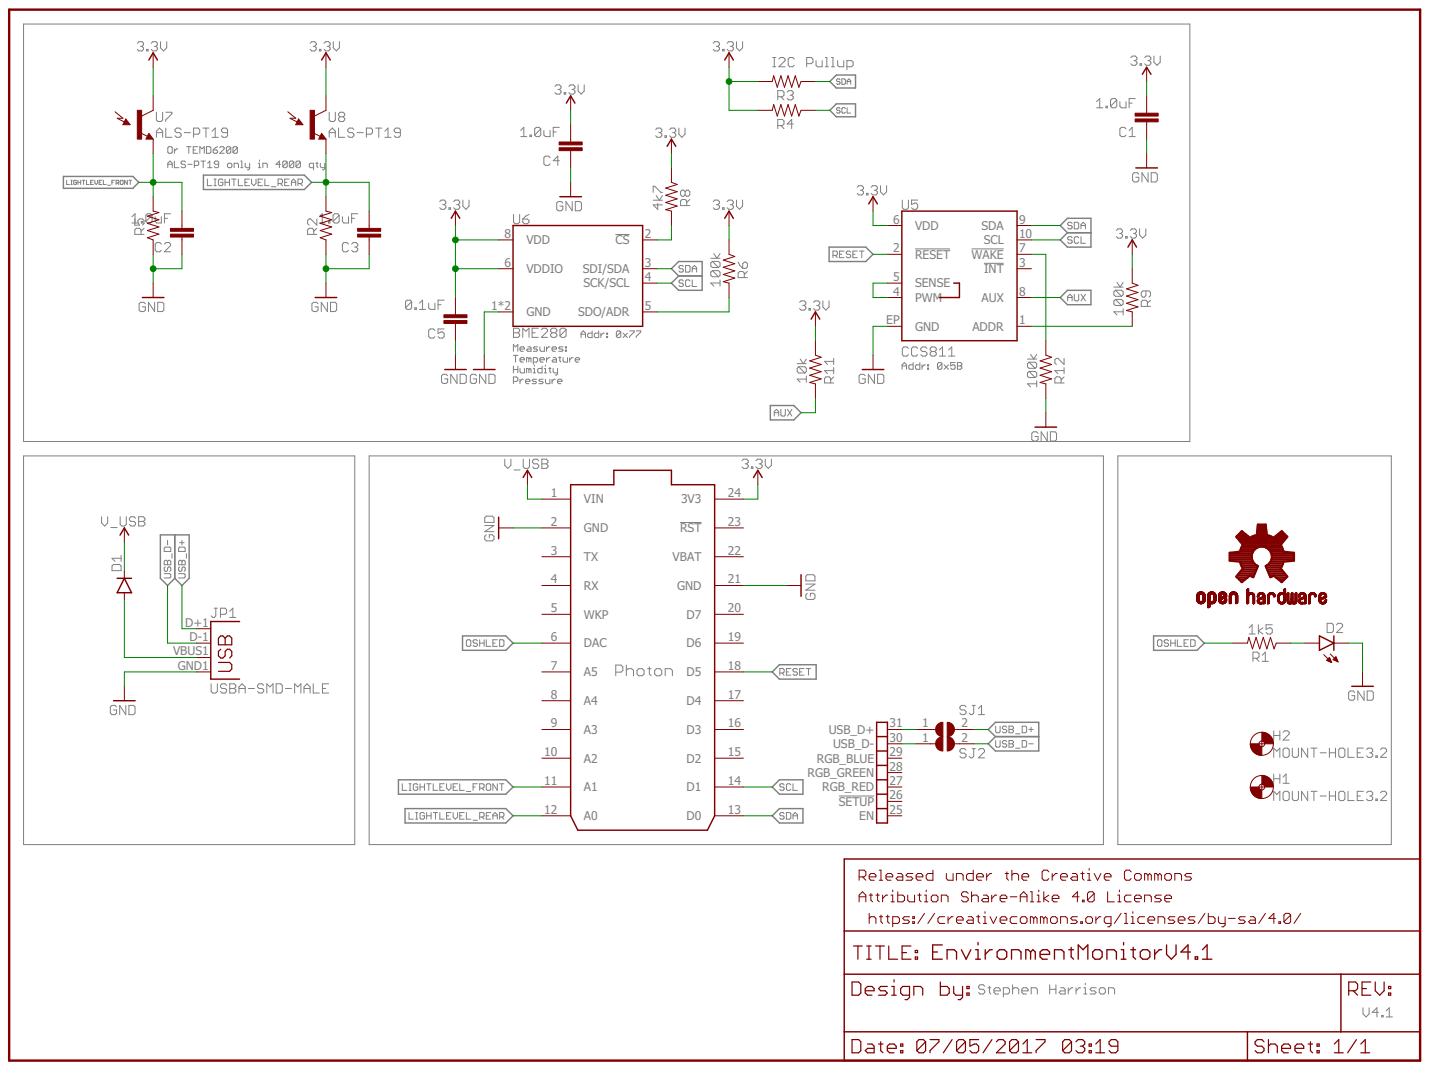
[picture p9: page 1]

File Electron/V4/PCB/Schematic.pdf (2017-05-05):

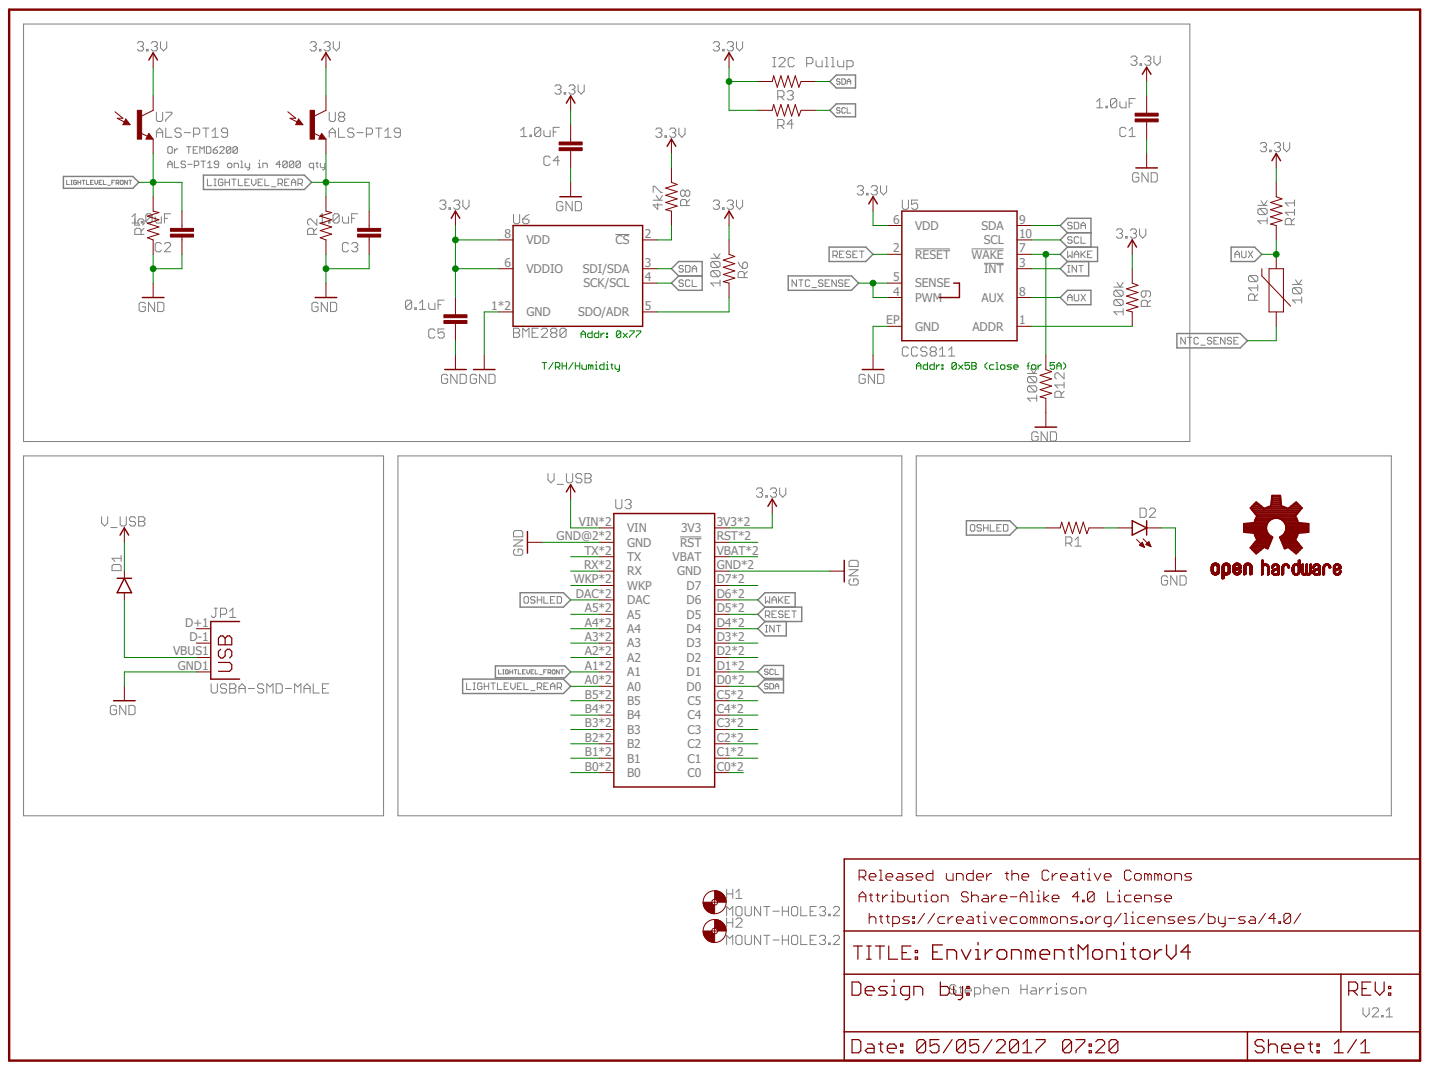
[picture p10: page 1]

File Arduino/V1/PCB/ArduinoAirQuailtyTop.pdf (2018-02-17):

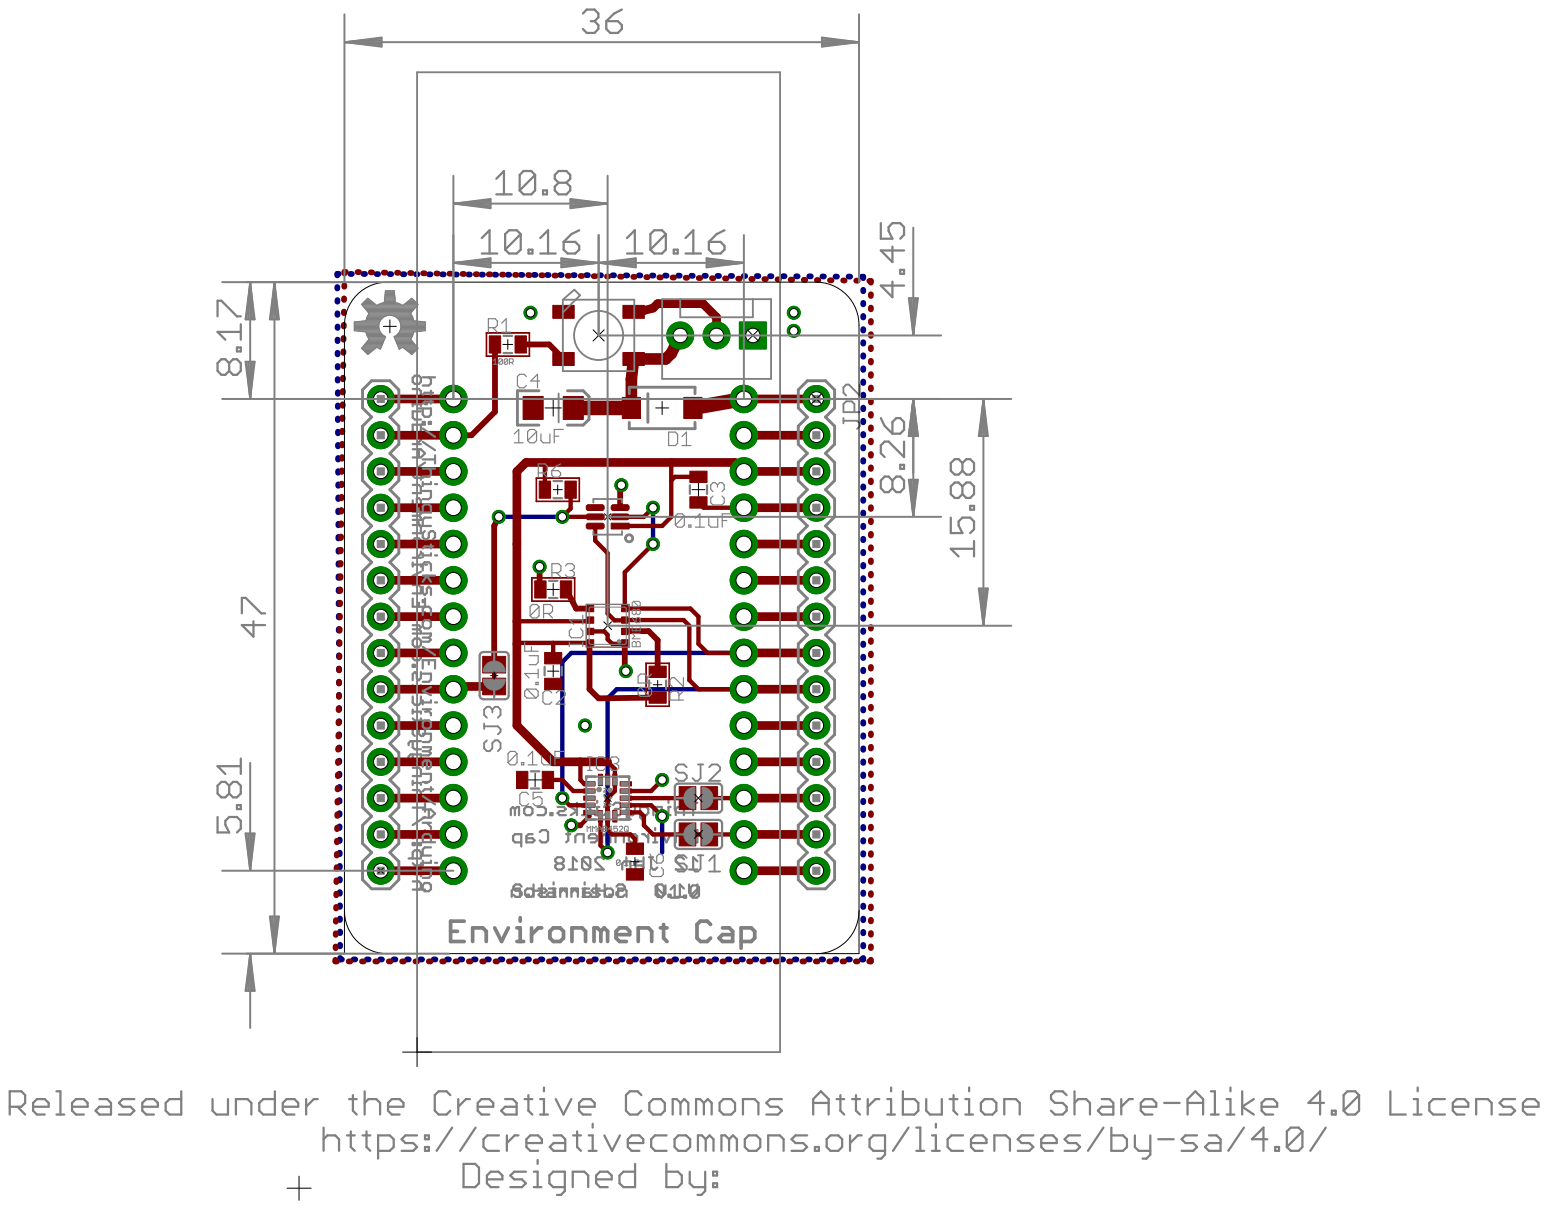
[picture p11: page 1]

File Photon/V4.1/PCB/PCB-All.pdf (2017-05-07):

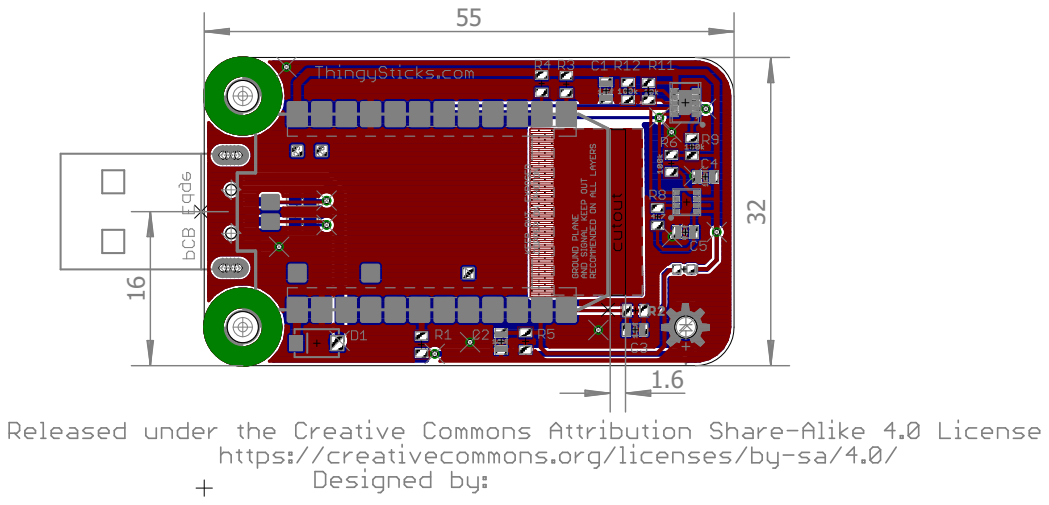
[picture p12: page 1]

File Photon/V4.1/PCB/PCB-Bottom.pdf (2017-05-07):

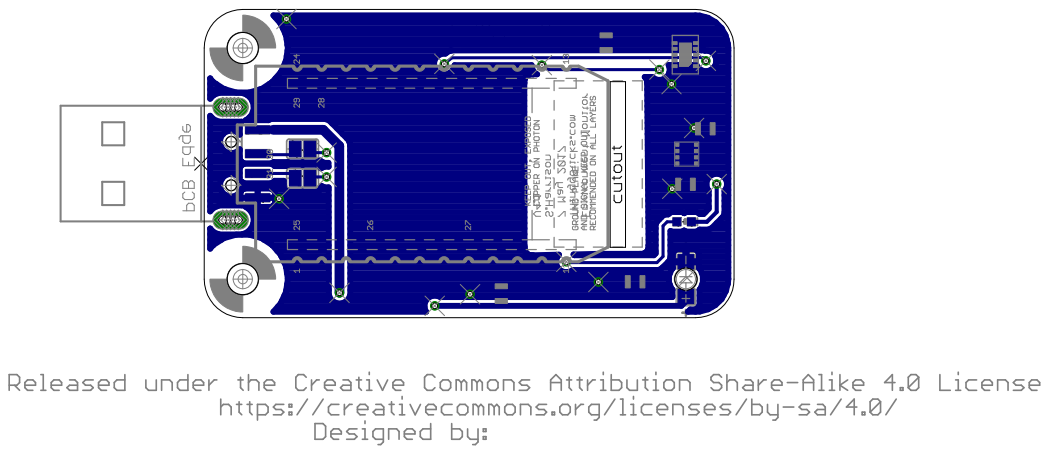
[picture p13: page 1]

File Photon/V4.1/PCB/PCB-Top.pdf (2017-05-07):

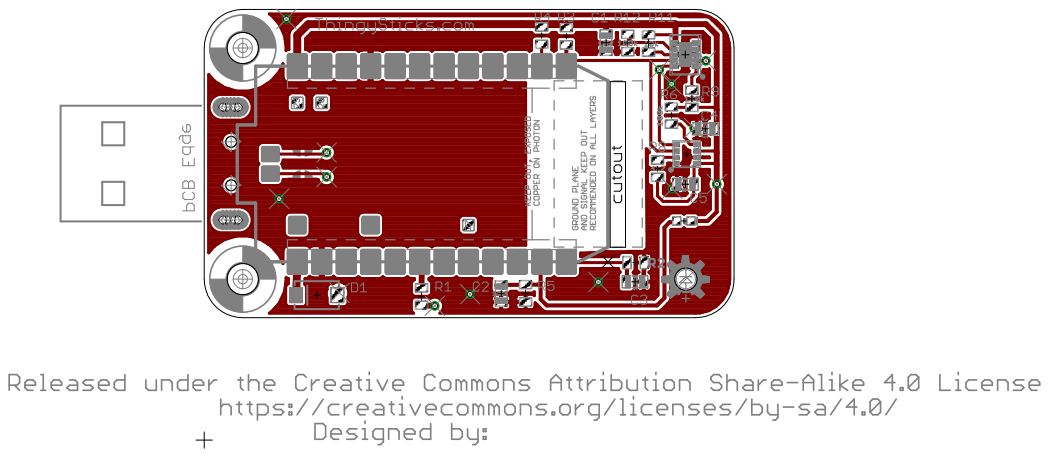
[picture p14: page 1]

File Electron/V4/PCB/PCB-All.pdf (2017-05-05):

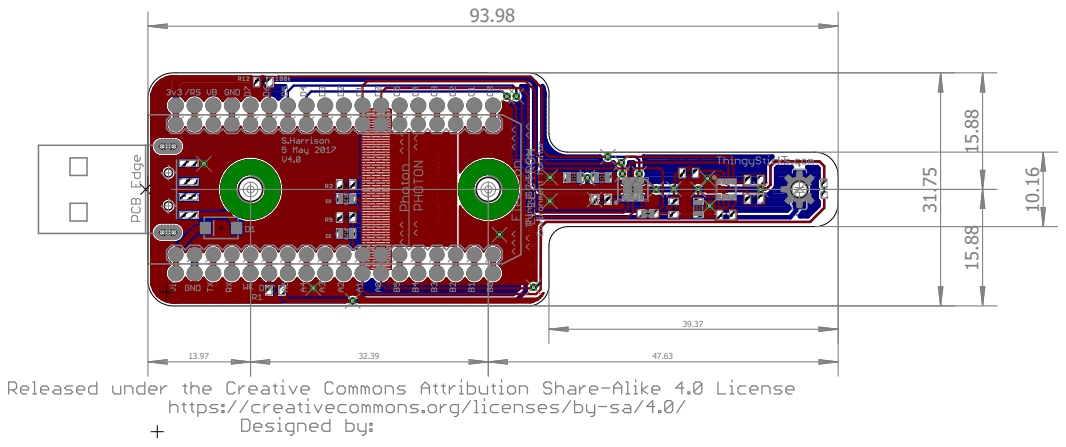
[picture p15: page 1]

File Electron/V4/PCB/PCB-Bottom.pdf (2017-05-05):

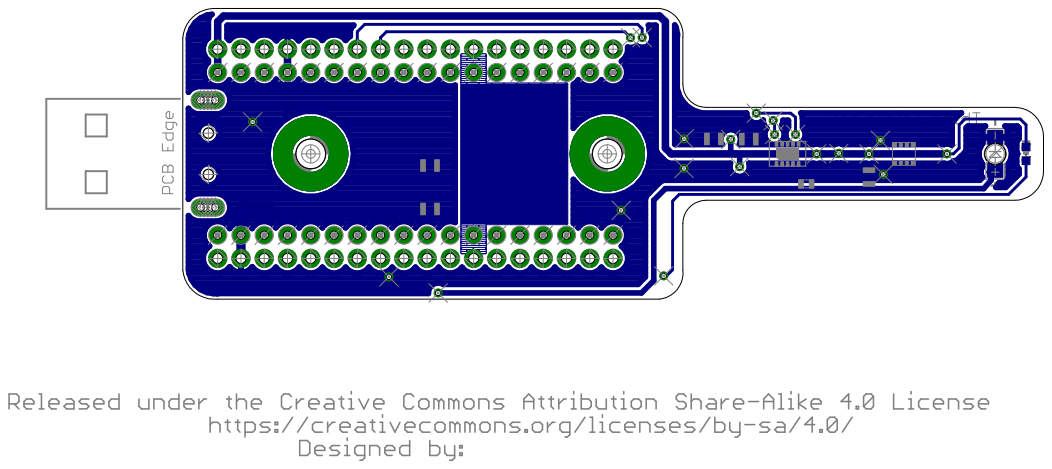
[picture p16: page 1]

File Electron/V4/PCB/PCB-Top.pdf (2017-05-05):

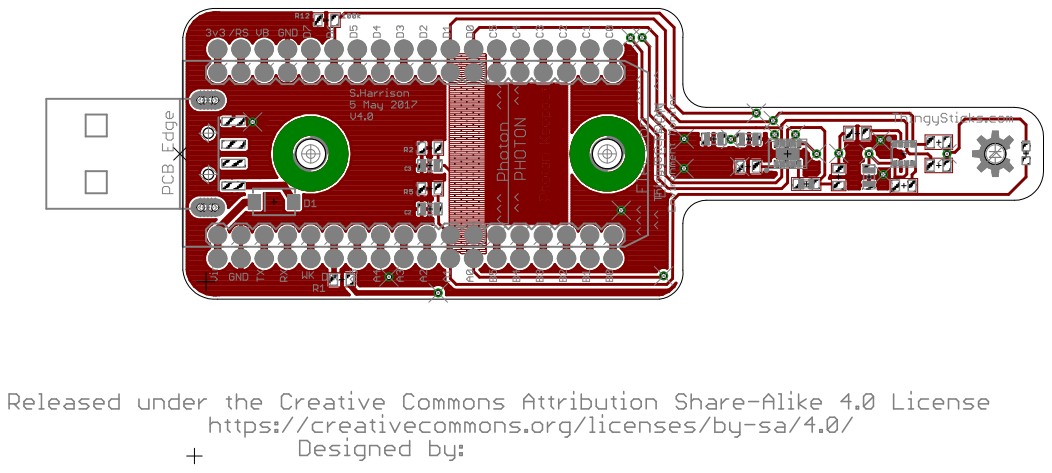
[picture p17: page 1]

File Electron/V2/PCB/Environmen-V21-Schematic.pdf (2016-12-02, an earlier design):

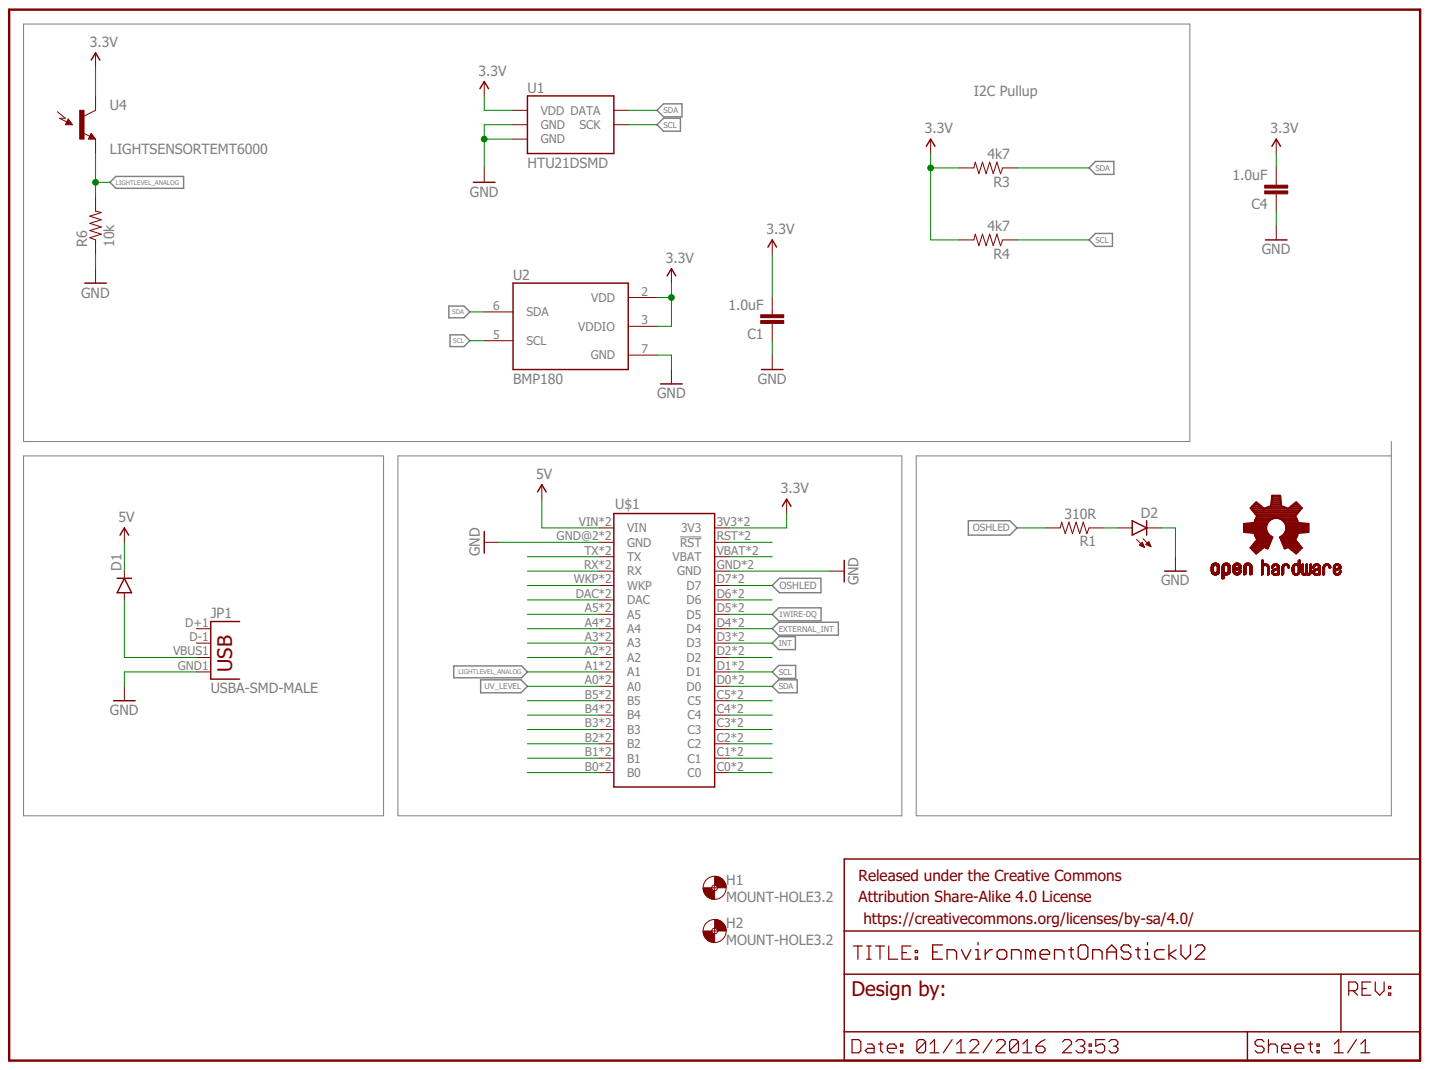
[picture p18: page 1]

Released under the Creative Commons Attribution Share-Alike 4.0 License https://creativecommons.org/licenses/by-sa/4.0/

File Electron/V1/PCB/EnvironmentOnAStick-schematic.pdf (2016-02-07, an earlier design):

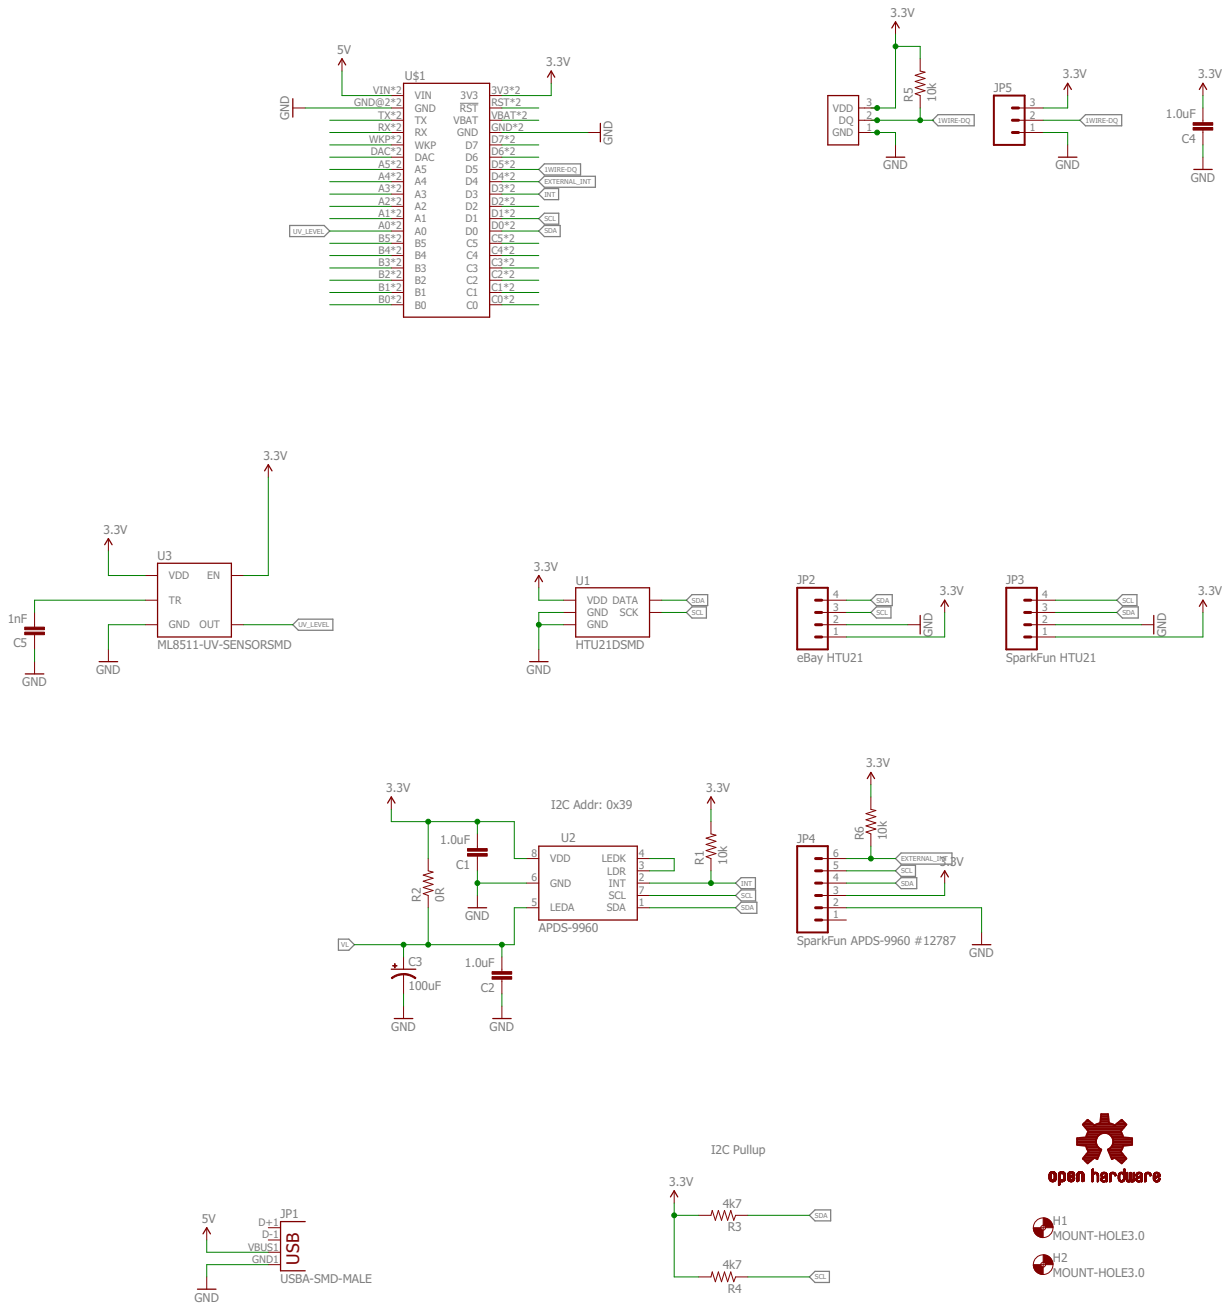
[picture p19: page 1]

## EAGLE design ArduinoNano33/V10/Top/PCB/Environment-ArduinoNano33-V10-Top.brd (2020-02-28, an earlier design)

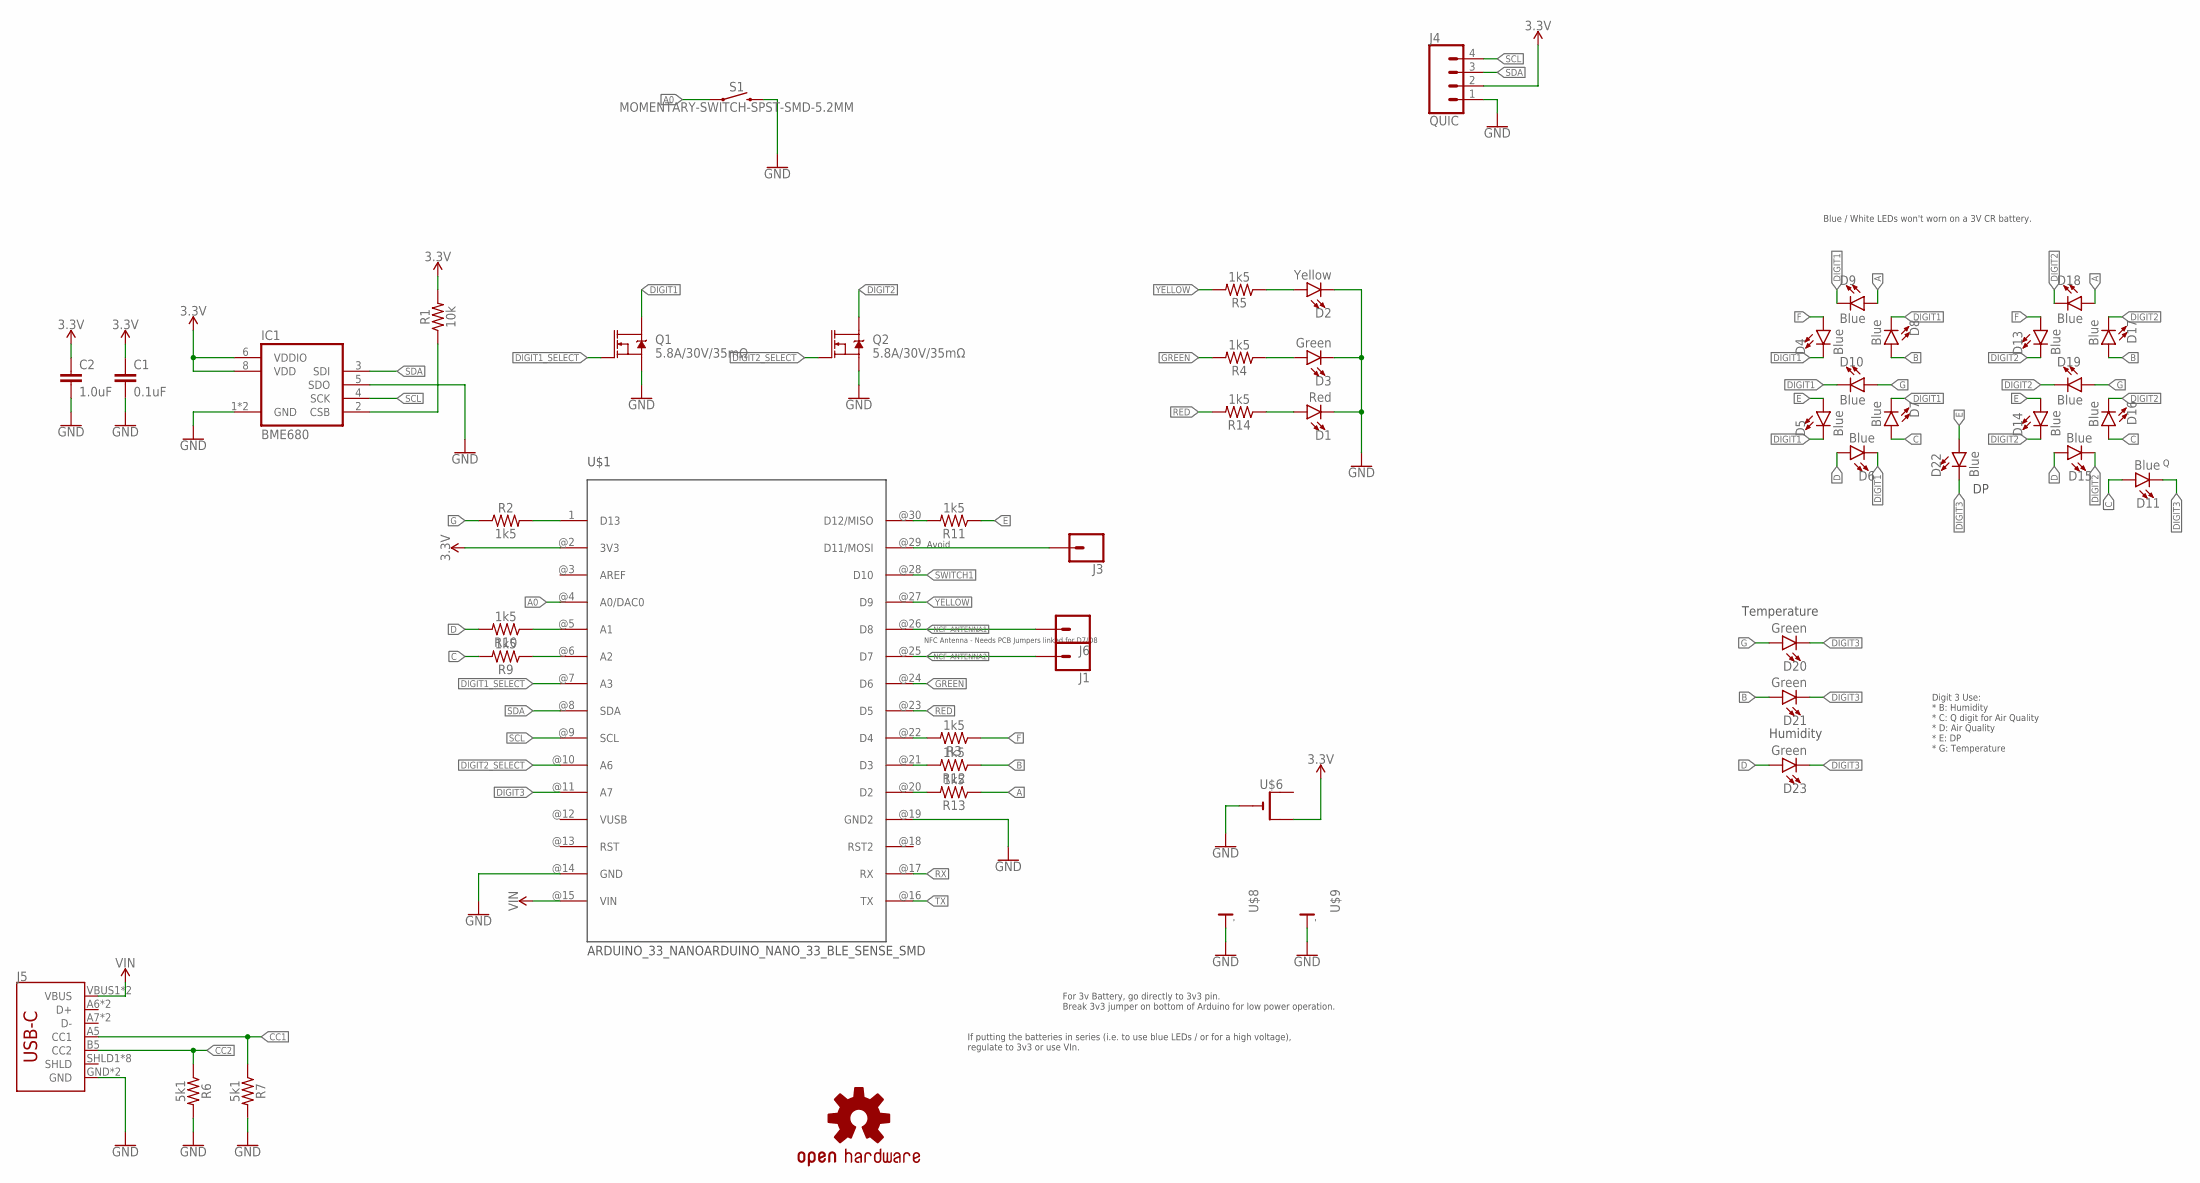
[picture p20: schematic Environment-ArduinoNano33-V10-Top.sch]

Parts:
C1: 0.1uF; 0805
C2: 1.0uF; 0805
D1: Red; LED-1206
D2: Yellow; LED-1206
D3, D20, D21, D23: Green; LED-1206
D4, D5, D6, D7, D8, D9, D10, D11, D13, D14, D15, D16, D17, D18, D19, D22: Blue; LED-1206
IC1: BME680
J1, J3, J6: CONN_01; 1X01
J4: QUIC; JST04_1MM_RA
J5: USB_C2-LAYER; USB-C-16P
LOGO1: OSHW-LOGOM; OSHW-LOGO-M
Q1, Q2: 5.8A/30V/35mΩ; SOT23-3
R1: 10k; 0805
R2, R3, R4, R5, R9, R10, R11, R12, R13, R14: 1k5; 0805
R6, R7: 5k1; 0805
S1: MOMENTARY-SWITCH-SPST-SMD-5.2MM; TACTILE_SWITCH_SMD_5.2MM
U$1: ARDUINO_33_NANOARDUINO_NANO_33_BLE_SENSE_SMD; ARDUINO_NANO_33_SMD
U$6: CR2032SMT; CR2032-SMD
U$8, U$9: CR2032-SPLIT-PCBCR2032-NEGATIVE; CR2032-SMD-NEGATIVE-TERMINAL

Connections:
3.3V: C1.1, C2.1, IC1.6 (VDDIO), IC1.8 (VDD), J4.2, R1.2, U$1.@2 (3V3), U$6.+$2 (+1)
A: D9.A, D18.A, R13.1
A0: S1.1, U$1.@4 (A0/DAC0)
B: D8.A, D17.A, D21.A, R12.1
C: D7.A, D11.A, D16.A, R9.2
CC1: J5.A5 (CC1), R7.1
CC2: J5.B5 (CC2), R6.1
D: D6.A, D15.A, D23.A, R10.2
DIGIT1: D4.C, D5.C, D6.C, D7.C, D8.C, D9.C, D10.C, Q1.3 (D)
DIGIT1_SELECT: Q1.1 (G), U$1.@7 (A3)
DIGIT2: D13.C, D14.C, D15.C, D16.C, D17.C, D18.C, D19.C, Q2.3 (D)
DIGIT2_SELECT: Q2.1 (G), U$1.@10 (A6)
DIGIT3: D11.C, D20.C, D21.C, D22.C, D23.C, U$1.@11 (A7)
E: D5.A, D14.A, D22.A, R11.1
F: D4.A, D13.A, R3.1
G: D10.A, D19.A, D20.A, R2.1
GND: C1.2, C2.2, D1.C, D2.C, D3.C, IC1.1 (GND), IC1.5 (SDO), IC1.7 (GND), J4.1, J5.GND, J5.GND2 (GND), Q1.2 (S), Q2.2 (S), R6.2, R7.2, S1.3 (2), U$1.@14 (GND), U$1.@19 (GND2), U$6.-, U$8.-, U$9.-
GREEN: R4.2, U$1.@24 (D6)
unnamed: IC1.2 (CSB), R1.1
unnamed: D1.A, R14.1
unnamed: R9.1, U$1.@6 (A2)
unnamed: R2.2, U$1.1 (D13)
unnamed: R11.2, U$1.@30 (D12/MISO)
unnamed: R12.2, U$1.@21 (D3)
unnamed: R10.1, U$1.@5 (A1)
unnamed: R13.2, U$1.@20 (D2)
unnamed: R3.2, U$1.@22 (D4)
unnamed: D3.A, R4.1
unnamed: D2.A, R5.1
unnamed: J3.1, U$1.@29 (D11/MOSI)
NCF_ANTENNA1: J6.1, U$1.@26 (D8)
NCF_ANTENNA2: J1.1, U$1.@25 (D7)
RED: R14.2, U$1.@23 (D5)
RX: U$1.@17 (RX)
SCL: IC1.4 (SCK), J4.4, U$1.@9 (SCL)
SDA: IC1.3 (SDI), J4.3, U$1.@8 (SDA)
SWITCH1: U$1.@28 (D10)
TX: U$1.@16 (TX)
VIN: J5.VBUS1 (VBUS), J5.VBUS2 (VBUS), U$1.@15 (VIN)
VUSB: U$1.@12 (VUSB)
YELLOW: R5.2, U$1.@27 (D9)

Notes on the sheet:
Temperature
Humidity
Avoid
NFC Antenna - Needs PCB Jumpers linked for D7/D8
Blue / White LEDs won't worn on a 3V CR battery.
For 3v Battery, go directly to 3v3 pin. Break 3v3 jumper on bottom of Arduino for low power operation.
If putting the batteries in series (i.e. to use blue LEDs / or for a high voltage), regulate to 3v3 or use VIn.
Digit 3 Use: * B: Humidity * C: Q digit for Air Quality * D: Air Quality * E: DP * G: Temperature

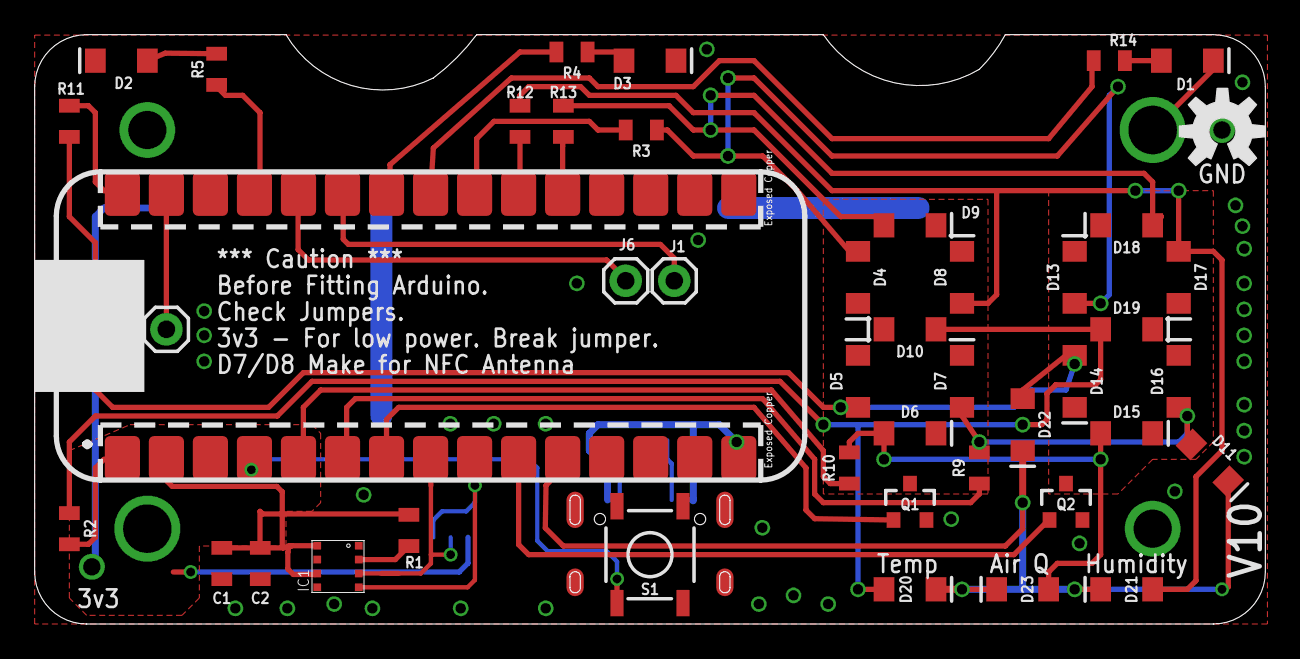
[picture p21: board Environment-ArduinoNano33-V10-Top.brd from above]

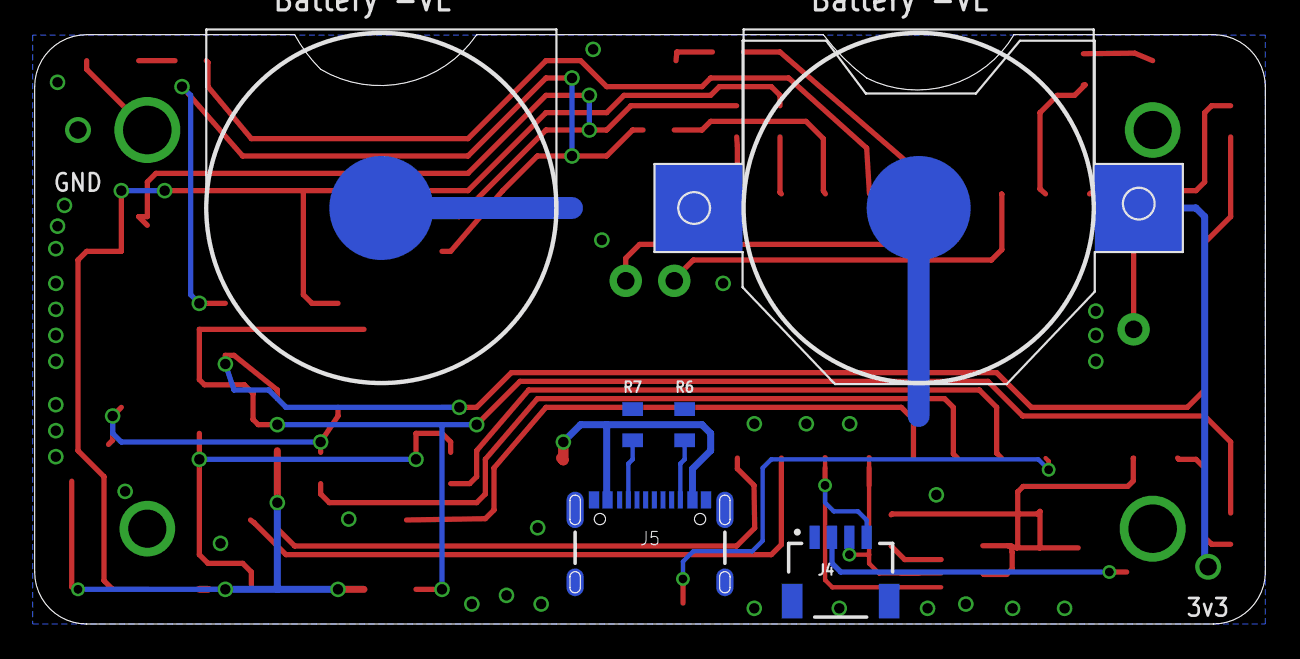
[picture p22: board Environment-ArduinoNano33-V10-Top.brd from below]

Board: 2 copper layers, 71.0 x 34.0 mm, 51 parts (7 on the bottom side), 37 nets.

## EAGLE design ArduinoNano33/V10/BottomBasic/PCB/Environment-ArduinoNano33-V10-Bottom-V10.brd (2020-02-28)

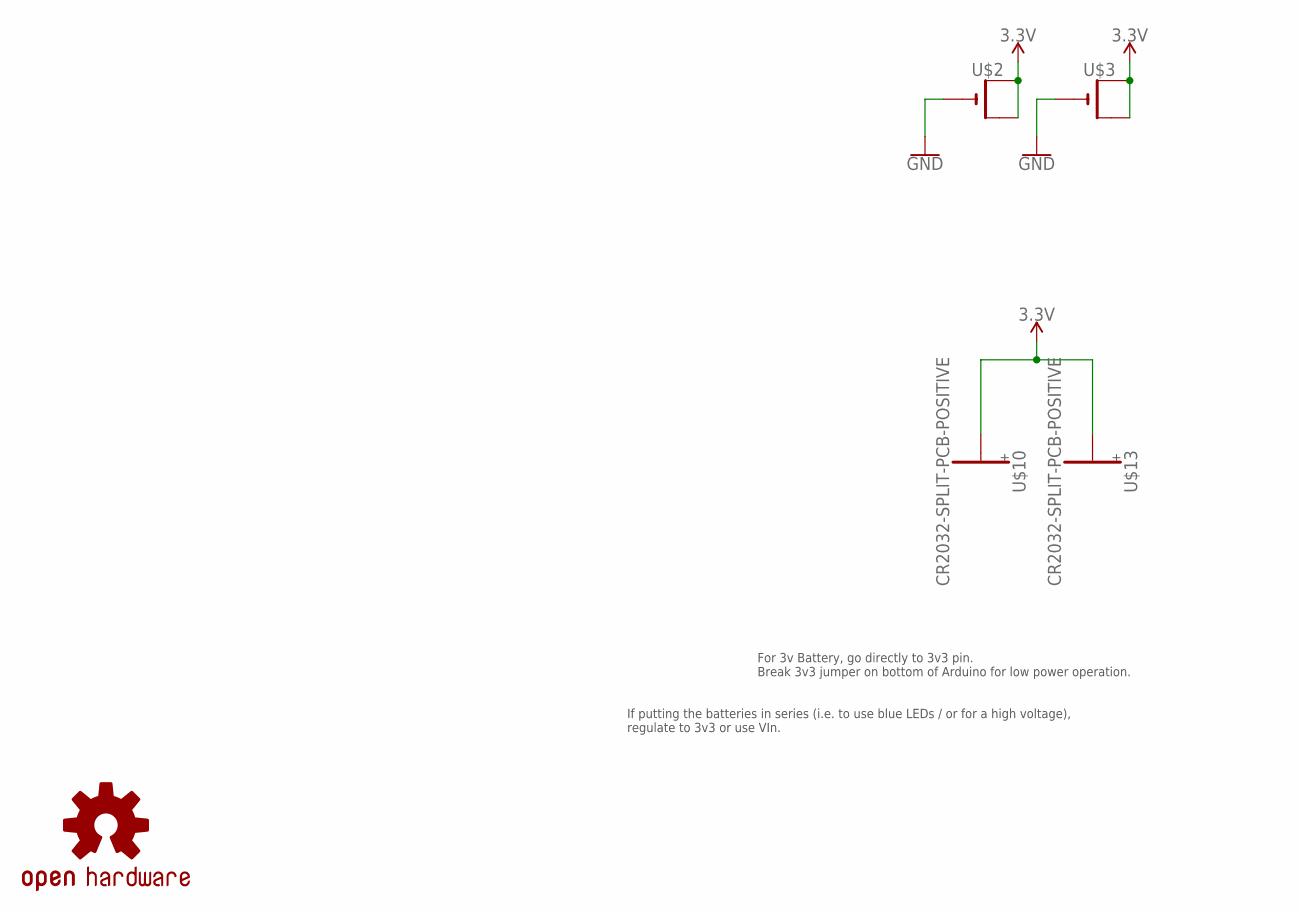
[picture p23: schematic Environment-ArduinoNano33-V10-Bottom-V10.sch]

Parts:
LOGO3: OSHW-LOGOL; OSHW-LOGO-L
U$2, U$3: CR2032SMT; CR2032-SMD
U$10, U$13: CR2032-SPLIT-PCB-POSITIVE; CR2032-SMD-POSITIVE-TERMINAL

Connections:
3.3V: U$2.+$1 (+), U$2.+$2 (+1), U$3.+$1 (+), U$3.+$2 (+1), U$10.+, U$13.+
GND: U$2.-, U$3.-

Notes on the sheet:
For 3v Battery, go directly to 3v3 pin. Break 3v3 jumper on bottom of Arduino for low power operation.
If putting the batteries in series (i.e. to use blue LEDs / or for a high voltage), regulate to 3v3 or use VIn.

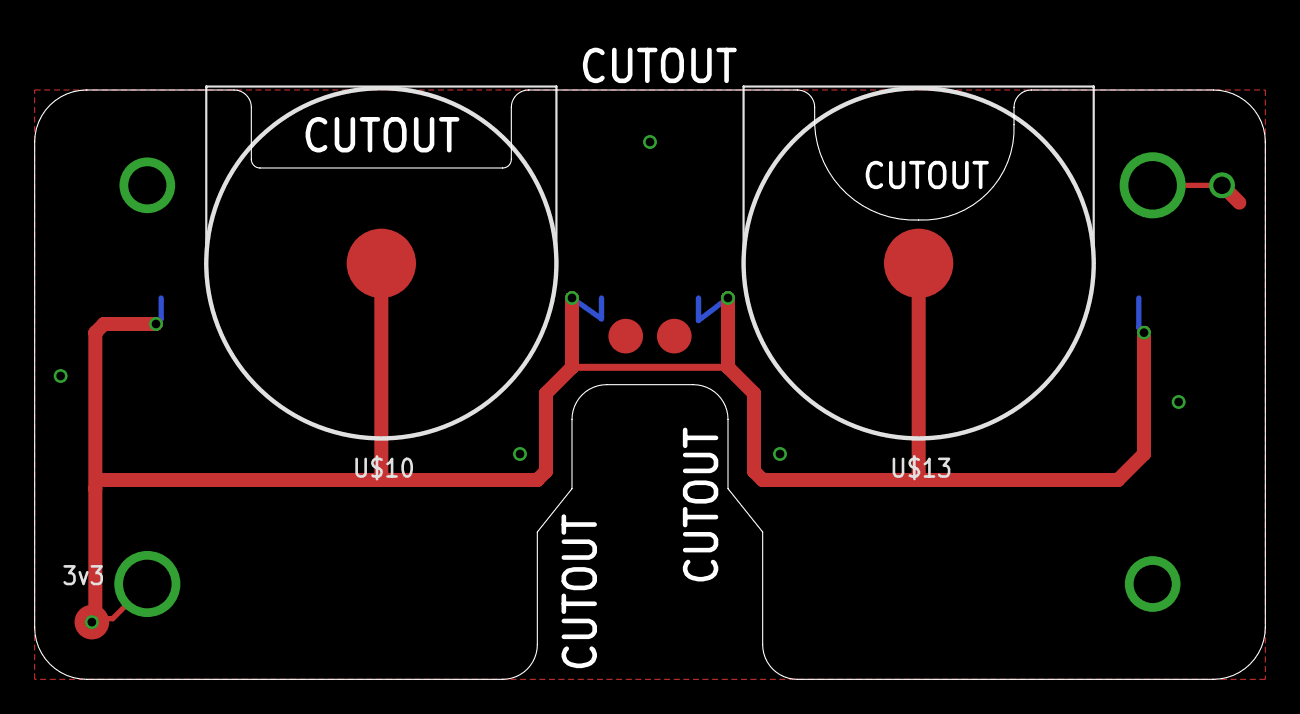
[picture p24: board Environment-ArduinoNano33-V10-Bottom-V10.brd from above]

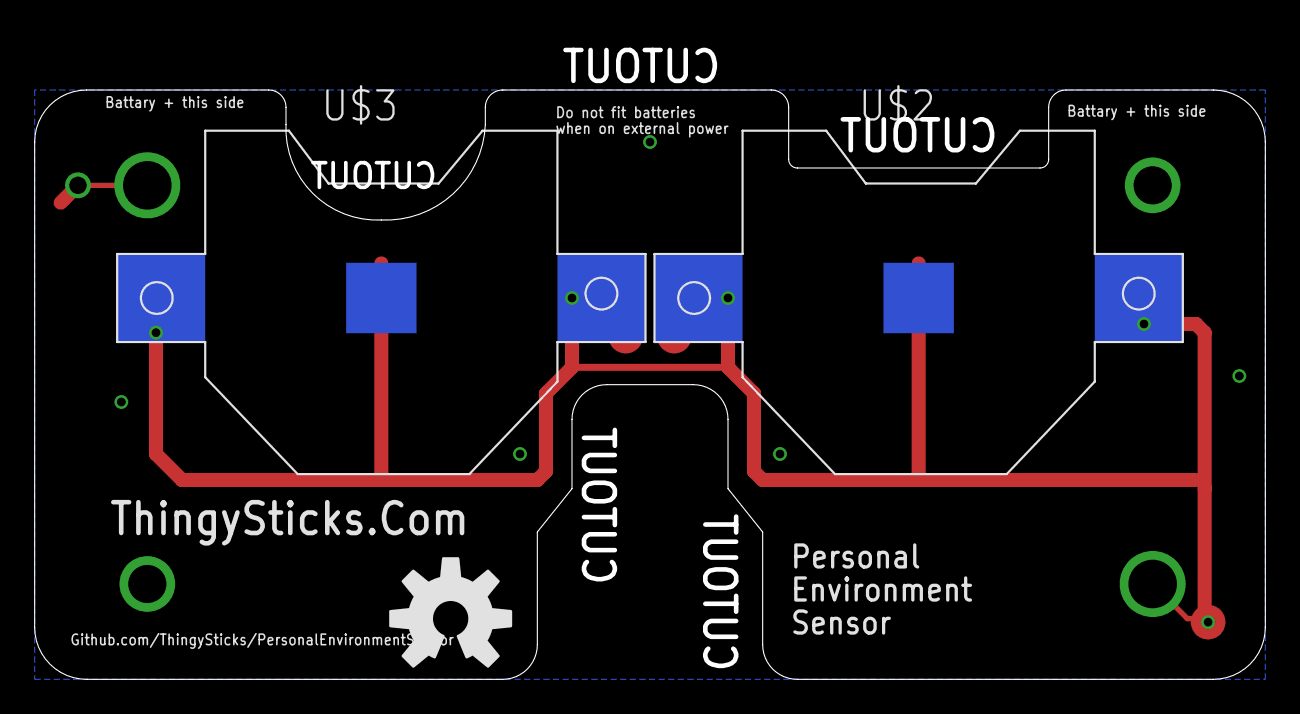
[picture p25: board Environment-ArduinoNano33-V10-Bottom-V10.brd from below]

Board: 2 copper layers, 71.0 x 34.0 mm, 5 parts (5 on the bottom side), 2 nets.

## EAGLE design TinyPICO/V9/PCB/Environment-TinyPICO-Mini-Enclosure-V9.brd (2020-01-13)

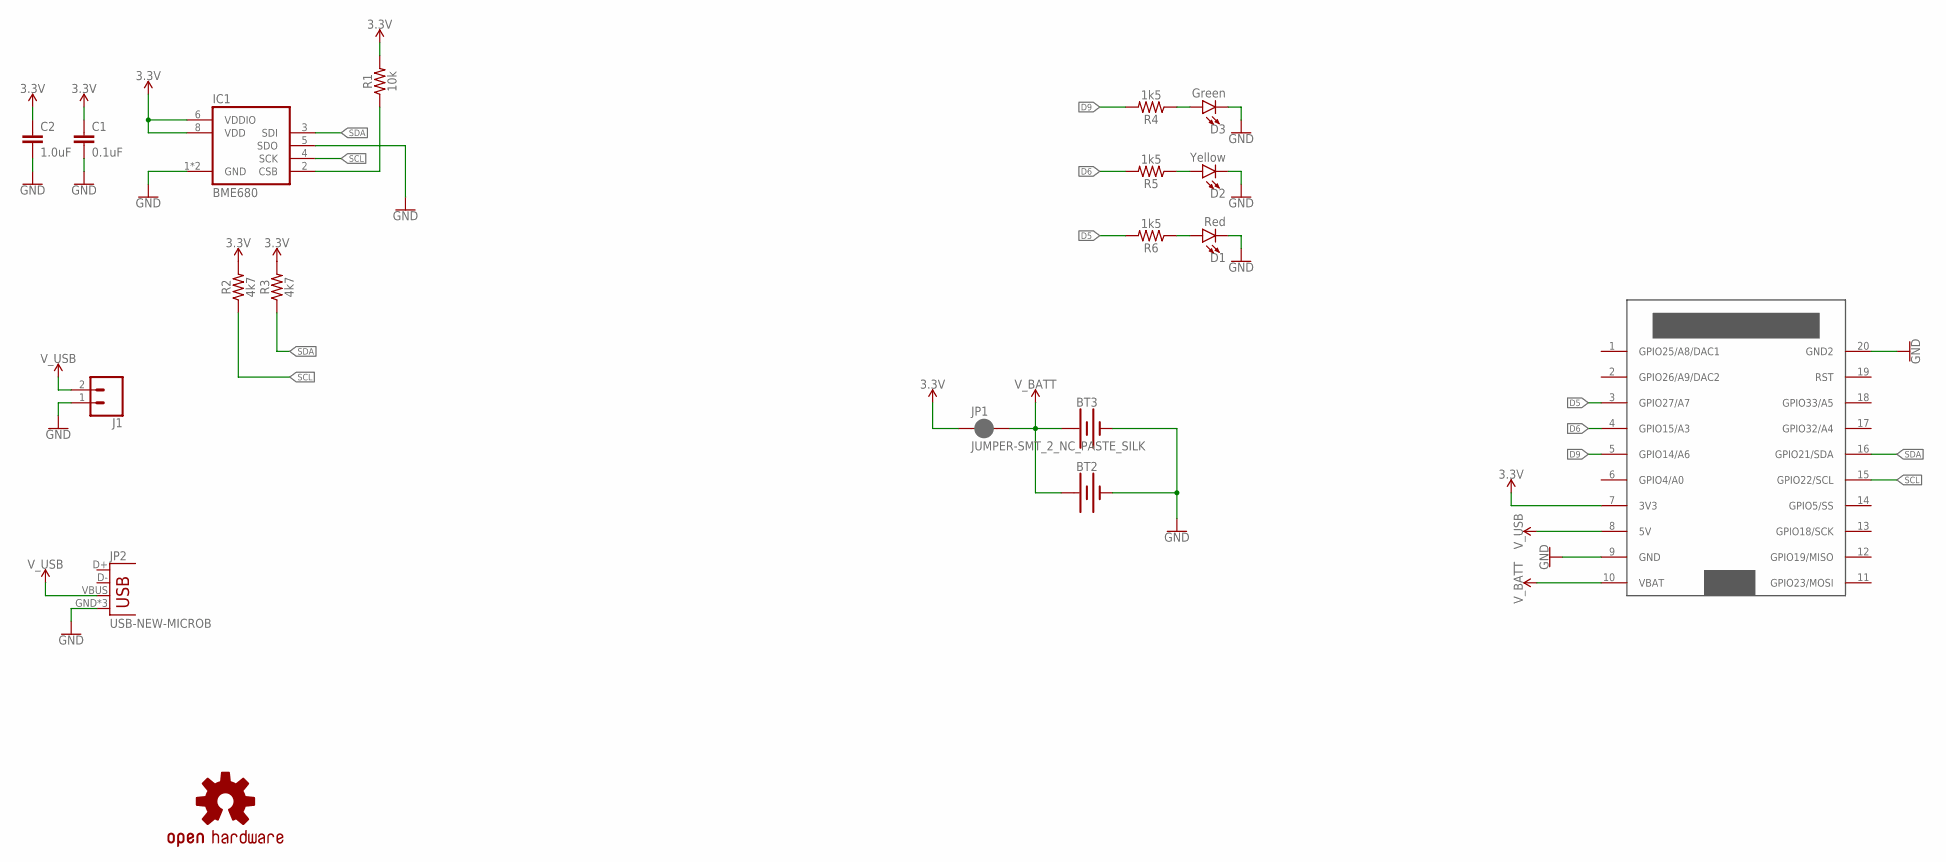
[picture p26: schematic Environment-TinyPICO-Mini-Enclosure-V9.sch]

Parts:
BT2, BT3: BATTERY-12MM_PTH; BATTCON_12MM_PTH
C1: 0.1uF; 0805
C2: 1.0uF; 0805
D1: Red; LED-1206
D2: Yellow; LED-1206
D3: Green; LED-1206
IC1: BME680
J1: CONN_02JST-2-PH-SIDE; JST-2-SMD
JP1: JUMPER-SMT_2_NC_PASTE_SILK; SMT-JUMPER_2_NC_PASTE_SILK
JP2: USB-NEW-MICROB; USB-MICROB
LOGO1: OSHW-LOGOM; OSHW-LOGO-M
R1: 10k; 0805
R2, R3: 4k7; 0805
R4, R5, R6: 1k5; 0805
U$2: TINY_PICO

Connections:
3.3V: C1.1, C2.1, IC1.6 (VDDIO), IC1.8 (VDD), JP1.1, R1.2, R2.2, R3.2, U$2.7 (3V3)
D5: R6.2, U$2.3 (GPIO27/A7)
D6: R5.2, U$2.4 (GPIO15/A3)
D9: R4.2, U$2.5 (GPIO14/A6)
GND: BT2.GND (-), BT3.GND (-), C1.2, C2.2, D1.C, D2.C, D3.C, IC1.1 (GND), IC1.5 (SDO), IC1.7 (GND), J1.1 (2), JP2.GND, JP2.MT1 (GND), JP2.MT2 (GND), U$2.9 (GND), U$2.20 (GND2)
unnamed: IC1.2 (CSB), R1.1
unnamed: D3.A, R4.1
unnamed: D2.A, R5.1
unnamed: D1.A, R6.1
SCL: IC1.4 (SCK), R2.1, U$2.15 (GPIO22/SCL)
SDA: IC1.3 (SDI), R3.1, U$2.16 (GPIO21/SDA)
V_BATT: BT2.VCC@1 (+), BT3.VCC@1 (+), JP1.2, U$2.10 (VBAT)
V_USB: J1.2 (1), JP2.VBUS, U$2.8 (5V)

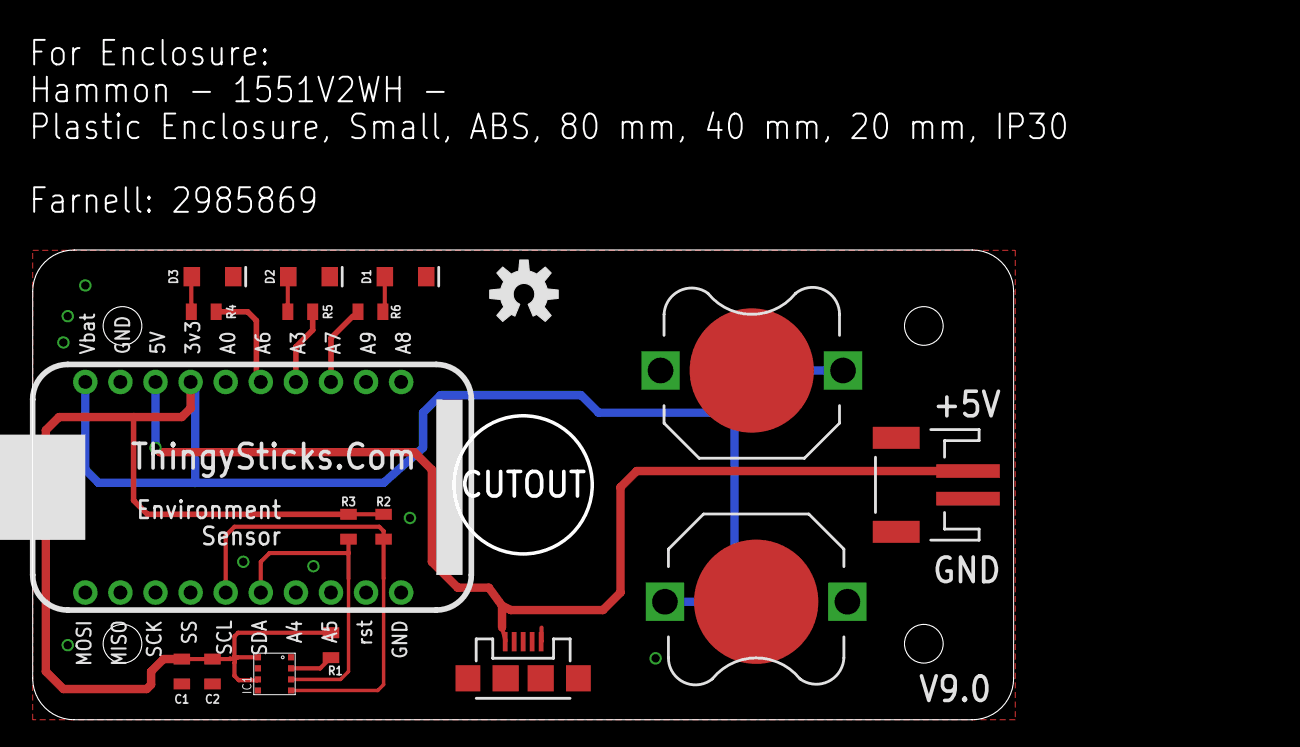
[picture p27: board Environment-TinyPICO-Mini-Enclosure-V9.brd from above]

Board: 2 copper layers, 71.0 x 34.0 mm, 19 parts (1 on the bottom side), 13 nets.

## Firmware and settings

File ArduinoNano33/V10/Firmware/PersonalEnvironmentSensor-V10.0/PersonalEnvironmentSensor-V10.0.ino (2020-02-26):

/*
  This example reads audio data from the on-board PDM microphones, and prints
  out the samples to the Serial console. The Serial Plotter built into the
  Arduino IDE can be used to plot the audio data (Tools -> Serial Plotter)

  Circuit:
  - Arduino Nano 33 BLE board

  This example code is in the public domain.
*/

#include <PDM.h>
#include <Arduino_LSM9DS1.h>
#include <Arduino_APDS9960.h>
#include <Arduino_LPS22HB.h>
#include <Arduino_HTS221.h>
#include <ArduinoBLE.h>

// RGB led 
const int rgbRedPin = 22;
const int rgbGreenPin = 23;
const int rgbBluePin = 24;

// PCB Red/Yellow/Green
const int pcbYellowPin = 9; // LHS
const int pcbGreenPin = 6; // Middle
const int pcbRedPin = 5; // RHS

const int LED_A = 2;
const int LED_B = 3;
const int LED_C = A2;
const int LED_D = A1;
const int LED_E = 12;
const int LED_F = 4;
const int LED_G = 13;

const int digit1 = A3;
const int digit2 = A6;
const int digit3 = A7;

const int switch1 = 10;


// TODO: Battery voltate monitor!
// TODO: Diode on battery!

// Low power notes:

// MP34DT05-A 1.6 - 3.6V. Tyical 1.8 (Mic)
// LSM9DS3  1.9 V to 3.6 V (Accel)
// APDS9960 2.4 - 3.6 (Typical 3.0) (Light)
// LPS22HB  1.7 to 3.6 V (Pressure)
// HTS221  1.7 to 3.6 V (Temperature / Humidity)
// NINA-B3 1.7 to 3.6 (Typical 3.3)
// DL3 - R + G + B LED (Blue won't work at 3v)

// Extra...
// BME680 1.71 to 3.6


// BLE Battery Service
//BLEService batteryService("180F");

// BLE Battery Level Characteristic
// standard 16-bit characteristic UUID
//BLEUnsignedCharCharacteristic batteryLevelChar("2A19",  BLERead | BLENotify);

// https://github.com/bneedhamia/DHTBLESensor/blob/master/DHTBLESensor.ino
//BLEService envService("181A");
//BLEUnsignedShortCharacteristic bleHumidityPC("2A6F", BLERead | BLENotify);
//BLEShortCharacteristic bleTemperatureC("2A6E", BLERead | BLENotify);

int oldBatteryLevel = 0;  // last battery level reading from analog input
long previousMillis = 0;  // last time the battery level was checked, in ms



// buffer to read samples into, each sample is 16-bits
short sampleBuffer[256];

// number of samples read
volatile int samplesRead;

// A, B, C, D, E, F, G
bool segments[][7] = {{true, true, true, true, true, true, false}, // 0
                      {false, true, true, false, false, false, false }, // 1
                      {true, true, false, true, true, false, true}, // 2
                      {true, true, true, true, false, false, true}, // 3
                      {false, true, true, false, false, true, true}, // 4
                      {true, false, true, true, false, true, true}, // 5
                      {true, false, true, true, true, true, true}, // 6
                      {true, true, true, false, false, false, false}, // 7
                      {true, true, true, true, true, true, true}, // 8
                      {true, true, true, true, false, true, true}, // 9
                      {true, true, true, false, true, true, true}, // A
                      {false, false, true, true, true, true, true}, // B
                      {true, false, false, true, true, true, false}, // C
                      {false, true, true, true, true, false, true}, // D
                      {true, false, false, true, true, true, true}, // E
                      {true, false, false, false, true, true, true}, // F
                      {true, true, true, true, true, true, false}, // Q (needs extra segment (C on Digit 3). // 16
                      {false, false, false, false, false, false, true}, // - 17
                      
};

void setup() {
  Serial.begin(9600);
  delay(2000);
  
  pinMode(LED_BUILTIN, OUTPUT); // initialize the built-in LED pin to indicate when a central is connected
  digitalWrite(LED_BUILTIN, HIGH);
  // RGB LED (DL3)
  //pinMode(rgbRedPin, OUTPUT);
  //pinMode(rgbGreenPin, OUTPUT);
  //pinMode(rgbBluePin, OUTPUT);

  pinMode(pcbRedPin, OUTPUT);
  pinMode(pcbYellowPin, OUTPUT);
  pinMode(pcbGreenPin, OUTPUT);

  pinMode(LED_A, OUTPUT);
  pinMode(LED_B, OUTPUT);
  pinMode(LED_C, OUTPUT);
  pinMode(LED_D, OUTPUT);
  pinMode(LED_E, OUTPUT);
  pinMode(LED_F, OUTPUT);
  pinMode(LED_G, OUTPUT);

  pinMode(digit1, OUTPUT);
  pinMode(digit2, OUTPUT);
  pinMode(digit3, OUTPUT);

  pinMode(switch1, INPUT_PULLUP);

  

  // Set the analog reference to 1v5 as wel 
  //analogReference(AR_INTERNAL1V65);

  // TODO: Analog in for battery voltage.

  // begin initialization
  /*
  if (!BLE.begin()) {
    Serial.println("starting BLE failed!");
    digitalWrite(pcbRedPin, HIGH);

    while (1);
  } else {
 
    // Set a local name for the BLE device
    // This name will appear in advertising packets
    // and can be used by remote devices to identify this BLE device
    // The name can be changed but maybe be truncated based on space left in advertisement packet
    

    
    BLE.setLocalName("environmentMonitor");
    
    BLE.setAdvertisedService(batteryService); // add the service UUID
    batteryService.addCharacteristic(batteryLevelChar); // add the battery level characteristic
    BLE.addService(batteryService); // Add the battery service
    
    batteryLevelChar.writeValue(oldBatteryLevel); // set initial value for this characteristic


    BLE.setAdvertisedService(envService);
    envService.addCharacteristic(bleTemperatureC); 
    envService.addCharacteristic(bleHumidityPC); 
    BLE.addService(envService); 

    bleTemperatureC.writeValue(1*100.0);
    bleHumidityPC.writeValue(1*100.0);
  
    // Start advertising BLE.  It will start continuously transmitting BLE
    // advertising packets and will be visible to remote BLE central devices
    // until it receives a new connection 
  
    // start advertising
    BLE.advertise();
  
    Serial.println("Bluetooth device active, waiting for connections...");
  }
  */
  
  
  // configure the audio data receive callback
  //PDM.onReceive(onPDMdata);

  // optionally set the gain, defaults to 20
  // PDM.setGain(30);

  // initialize PDM with:
  // - one channel (mono mode)
  // - a 16 kHz sample rate
  /*
  if (!PDM.begin(1, 16000)) {
    Serial.println("Failed to start PDM!");
    while (1);
  }
  */


  // Temperature / Humidity.


  if (!HTS.begin()) {
    digitalWrite(pcbRedPin, HIGH);
    Serial.println("Failed to initialize humidity temperature sensor!");
    while (1);
  }

/*
  if (!BARO.begin()) {
    Serial.println("Failed to initialize pressure sensor!");
    while (1);
  }

  if (!APDS.begin()) {
    Serial.println("Error initializing APDS9960 sensor!");
  }

  if (!IMU.begin()) {
    Serial.println("Failed to initialize IMU!");
    while (1);
  }
  */
  //digitalWrite(LED_BUILTIN, LOW);
}

float temperature;
float humidity;
float pressure;

void checkTemperature() {
  temperature = HTS.readTemperature();
  humidity    = HTS.readHumidity();
  pressure = BARO.readPressure();

  Serial.print("Temperature = ");
  Serial.print(temperature);
  Serial.println(" °C");

   Serial.print("Humidity    = ");
  Serial.print(humidity);
  Serial.println(" %");

  Serial.print("Pressure = ");
  Serial.print(pressure);
  Serial.println(" kPa");
}

/*

void checkLightLevels() {
  while (! APDS.colorAvailable()) {
    delay(5);
  }
  
  int r, g, b;
  APDS.readColor(r, g, b);
  
  Serial.print("Colour:  ");
  Serial.print('\t');
  Serial.print("r = ");
  Serial.print(r);
  Serial.print('\t');
  Serial.print("g = ");
  Serial.print(g);
  Serial.print('\t');
  Serial.print("b = ");
  Serial.print(b);
  Serial.println();
}

float x, y, z;
 
void checkAcceleration() {
 

  if (IMU.accelerationAvailable()) {
        IMU.readAcceleration(x, y, z);

        Serial.print("Accel: ");
        Serial.print('\t');
        
        Serial.print(x);
        Serial.print('\t');
        Serial.print(y);
        Serial.print('\t');
        Serial.println(z);
  }

}

void checkGyro() {
  if (IMU.gyroscopeAvailable()) {
        IMU.readGyroscope(x, y, z);

        Serial.print("Gyro: ");
        Serial.print('\t');
        Serial.print(x);
        Serial.print('\t');
        Serial.print(y);
        Serial.print('\t');
        Serial.println(z);
  }
}

void checkMagneticField() {

  if (IMU.magneticFieldAvailable()) {
        IMU.readMagneticField(x, y, z);

        Serial.print("Magnetic Field: ");
        Serial.print('\t');
        Serial.print(x);
        Serial.print('\t');
        Serial.print(y);
        Serial.print('\t');
        Serial.println(z);
  }
}

*/


void showDigit(int value) {

  if (value < 0) {
    digitalWrite(LED_A, LOW);
    digitalWrite(LED_B, LOW);
    digitalWrite(LED_C, LOW);
    digitalWrite(LED_D, LOW);
    digitalWrite(LED_E, LOW);
    digitalWrite(LED_F, LOW);
    digitalWrite(LED_G, LOW);
  } else {
    digitalWrite(LED_A, segments[value][0]);
    digitalWrite(LED_B, segments[value][1]);
    digitalWrite(LED_C, segments[value][2]);
    digitalWrite(LED_D, segments[value][3]);
    digitalWrite(LED_E, segments[value][4]);
    digitalWrite(LED_F, segments[value][5]);
    digitalWrite(LED_G, segments[value][6]);
  }
}

void showNumber(float value, bool temperature, bool humidity, bool airQuality, int delayms) {

  int intValue = 0;
  int digit1value = -1;
  int digit2value = -1;
  bool dp = false;
  bool q = false;

  if (value < -9) {
    // We can't show this.
    digit1value = 17; // -
    digit2value = 17; // -
  } else if (value < 0) {
    // Show negative.
    digit1value = 17; // -ve
    // Cast to integer and make +ve (i.e. -6.1 -> 6)
    digit2value = - ((int)value);
  } else if (value >-0.1 && value < 0.1) {
    // 0.0
    digit1value = 0;
    digit2value = 0;
    dp = true;
  } else if (value < 10) {
    // Single digit so we can show x.x
    intValue = (int) (value * 10); // 3.4 -> 34
    
    digit1value = intValue / 10;
    digit2value = intValue - (digit1value * 10);
    dp = true;
  } else if (value > 99) {
    // out of range
    digit1value = 17;
    digit2value = 17;
  }
  else {
    digit1value = value / 10; // 17 -> 1
    digit2value = value - (digit1value * 10); // (17 -> 7)
  }


  // Now light up the LEDs to show the digit values...
  int digitDelay = 2;  
  for (int i = 0; i< (delayms / digitDelay); i++) {
    
    for (int digit=0; digit<3; digit++) {
      
      // All off whilst we setup the segments.
      enableDigit(0);

      if (digit == 0) {
        showDigit(digit1value);
      } else if (digit == 1) {
        showDigit(digit2value);
      } else {
        // Digit 3.
        digitalWrite(LED_A, false);
        digitalWrite(LED_B, humidity);
        digitalWrite(LED_C, q);
        digitalWrite(LED_D, airQuality);
        digitalWrite(LED_E, dp);
        digitalWrite(LED_F, false);
        digitalWrite(LED_G, temperature);
      }

      enableDigit(digit+1);
      delay(digitDelay);
    }
    
  }
}

void enableDigit(int digit) {
      // Enable the appropriate digit.
      switch (digit) {
        case 1:
          digitalWrite(digit1, HIGH);
          digitalWrite(digit2, LOW);
          digitalWrite(digit3, HIGH);  
          break;
        case 2:
          digitalWrite(digit1, LOW);
          digitalWrite(digit2, HIGH);
          digitalWrite(digit3, HIGH);  
          break;
        case 3:
          digitalWrite(digit1, LOW);
          digitalWrite(digit2, LOW);
          digitalWrite(digit3, LOW);   // digit 3 is active low.
          break;
        default:
          // all off.
          digitalWrite(digit1, LOW);
          digitalWrite(digit2, LOW);
          digitalWrite(digit3, HIGH);  
          break;
      }  
}

int loopCounter = 0;

void loop() {

  // wait for a BLE central
  //BLEDevice central = BLE.central();
  //handleBLE(central);

  digitalWrite(pcbRedPin, LOW);
  digitalWrite(pcbYellowPin, LOW);
  digitalWrite(pcbGreenPin, LOW);
  
  //readAudioData();
  checkTemperature();   
  //checkLightLevels();
  //checkAcceleration();
  //checkGyro();
  //checkMagneticField();

  boolean switchPressed = !digitalRead(switch1);

  if (loopCounter == 0) {
    Serial.println("All Off");
    digitalWrite(digit1, LOW);
    digitalWrite(digit2, LOW);
    digitalWrite(digit3, HIGH); 
    delay(500);
  }
  
  if (loopCounter == 1) {
    Serial.println("Digit 1");
    digitalWrite(digit1, HIGH);
    digitalWrite(digit2, LOW);
    digitalWrite(digit3, HIGH); 
    for (int i=0; i<16; i++) {
      Serial.println(i, DEC);
      showDigit(i);
      delay(300);
    }
  }
  
  if (loopCounter == 2) {
    Serial.println("Digit 2");
    digitalWrite(digit1, LOW);
    digitalWrite(digit2, HIGH);
    digitalWrite(digit3, HIGH); 
    for (int i=0; i<16; i++) {
      Serial.println(i, DEC);
      showDigit(i);
      delay(300);
    }
  }
  
  if (loopCounter == 3) {
    Serial.println("Number range");
    for (float t = -10; t<20; t++) {
      Serial.println(t, DEC);
      showNumber(t, false, false, false, 60);
    }
  }

  if (loopCounter == 4) {
    Serial.println("All Off");
    digitalWrite(digit1, LOW);
    digitalWrite(digit2, LOW);
    digitalWrite(digit3, HIGH); 
    delay(1000);
  }

  if (loopCounter == 5) {
    Serial.println("Temperature");
    showNumber(temperature, true, false, false, 2000);
  }

  if (loopCounter == 6) {
    Serial.println("Humidity");
    showNumber(humidity, false, true, false, 2000);
  }

  if (loopCounter == 7) {
    Serial.println("Air Q");
    showNumber(9.1, false, false, true, 1000);
  }
  
  if (loopCounter == 8) { // HS
    Serial.println("Yellow");
    enableDigit(0);
    digitalWrite(pcbYellowPin, HIGH);
    delay(500);
  }

  if (loopCounter == 9) { // Middle
    Serial.println("Green");
    enableDigit(0);
    digitalWrite(pcbGreenPin, HIGH);
    delay(500);
  }

  if (loopCounter == 10) {
    Serial.println("Red"); //RHS
    enableDigit(0);
    digitalWrite(pcbRedPin, HIGH);
    delay(500);
  }

  if (loopCounter == 11) {
    Serial.println("Red"); //RHS
    enableDigit(0);
    digitalWrite(pcbRedPin, HIGH);
    delay(500);

    for (int i=0; i<30; i++) {
      checkTemperature();  

      digitalWrite(pcbGreenPin, LOW);
      digitalWrite(pcbYellowPin, LOW);
      digitalWrite(pcbRedPin, LOW);

      if (temperature > 29) {
        digitalWrite(pcbGreenPin, HIGH);
        digitalWrite(pcbYellowPin, LOW);
        digitalWrite(pcbRedPin, LOW);  
      }else if (temperature > 27) {
        digitalWrite(pcbGreenPin, LOW);
        digitalWrite(pcbYellowPin, HIGH);
        digitalWrite(pcbRedPin, LOW);  
      } else {
        digitalWrite(pcbGreenPin, LOW);
        digitalWrite(pcbYellowPin, LOW);
        digitalWrite(pcbRedPin, LOW);  
      }
      
      showNumber(temperature, true, false, false, 1000);
      showNumber(humidity, false, true, false, 800);
    }
  }
  
  loopCounter++;
  
  Serial.print("Loop Counter: ");
  Serial.println(loopCounter, DEC);

  if (loopCounter > 12) {
    loopCounter = 0;
  }
}

/*
void readAudioData() {
    // wait for samples to be read
  if (samplesRead) {

    // print samples to the serial monitor or plotter
    for (int i = 0; i < samplesRead; i++) {
      Serial.println(sampleBuffer[i]);
    }

    // clear the read count
    samplesRead = 0;
  }
}

void handleBLE(BLEDevice central) {
  // if a central is connected to the peripheral:
  if (central) {
    Serial.print("Connected to central: ");
    // print the central's BT address:
    Serial.println(central.address());
    // turn on the LED to indicate the connection:
    //digitalWrite(LED_BUILTIN, HIGH);

    // check the battery level every 200ms
    // while the central is connected:
    while (central.connected()) {
      long currentMillis = millis();
      // if 1000ms have passed, check the battery level:
      if (currentMillis - previousMillis >= 1000) {
        previousMillis = currentMillis;
        updateBatteryLevel();
      }
    }
    // when the central disconnects, turn off the LED:
    //digitalWrite(LED_BUILTIN, LOW);
    Serial.print("Disconnected from central: ");
    Serial.println(central.address());
  }
}

// TODO: Convert to sound level
void onPDMdata() {
  // query the number of bytes available
  //int bytesAvailable = PDM.available();

  // read into the sample buffer
  //PDM.read(sampleBuffer, bytesAvailable);

  // 16-bit, 2 bytes per sample
  //samplesRead = bytesAvailable / 2;
}


void updateBatteryLevel() {
  // Read the current voltage level on the A0 analog input pin.
  //   This is used here to simulate the charge level of a battery.
  
  int battery = analogRead(A0);
  int batteryLevel = map(battery, 0, 1023, 0, 100);

  if (batteryLevel != oldBatteryLevel) {      // if the battery level has changed
    Serial.print("Battery Level % is now: "); // print it
    Serial.println(batteryLevel);
    batteryLevelChar.writeValue(batteryLevel);  // and update the battery level characteristic
    oldBatteryLevel = batteryLevel;           // save the level for next comparison
  }

   short newTemperatureC = (short) (temperature * 100.0);
   bleTemperatureC.setValue(newTemperatureC);
   
   unsigned short newHumidity = (unsigned short) (humidity * 100.0);
   bleHumidityPC.setValue(newHumidity);
}
*/

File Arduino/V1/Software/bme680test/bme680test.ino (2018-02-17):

/***************************************************************************
  This is a library for the BME680 gas, humidity, temperature & pressure sensor

  Designed specifically to work with the Adafruit BME680 Breakout
  ----> http://www.adafruit.com/products/3660

  These sensors use I2C or SPI to communicate, 2 or 4 pins are required
  to interface.

  Adafruit invests time and resources providing this open source code,
  please support Adafruit and open-source hardware by purchasing products
  from Adafruit!

  Written by Limor Fried & Kevin Townsend for Adafruit Industries.
  BSD license, all text above must be included in any redistribution
 ***************************************************************************/

#include <Wire.h>
#include <SPI.h>
#include <Adafruit_Sensor.h>
#include "Adafruit_BME680.h"

#define SEALEVELPRESSURE_HPA (1013.25)

Adafruit_BME680 bme; // I2C

void setup() {
  Serial.begin(9600);
  while (!Serial);
  Serial.println(F("BME680 test"));

  if (!bme.begin()) {
    Serial.println("Could not find a valid BME680 sensor, check wiring!");
    while (1);
  }

  // Set up oversampling and filter initialization
  bme.setTemperatureOversampling(BME680_OS_8X);
  bme.setHumidityOversampling(BME680_OS_2X);
  bme.setPressureOversampling(BME680_OS_4X);
  bme.setIIRFilterSize(BME680_FILTER_SIZE_3);
  bme.setGasHeater(320, 150); // 320*C for 150 ms
}

void loop() {
  if (! bme.performReading()) {
    Serial.println("Failed to perform reading :(");
    return;
  }
  Serial.print("Temperature = ");
  Serial.print(bme.temperature);
  Serial.println(" *C");

  Serial.print("Pressure = ");
  Serial.print(bme.pressure / 100.0);
  Serial.println(" hPa");

  Serial.print("Humidity = ");
  Serial.print(bme.humidity);
  Serial.println(" %");

  Serial.print("Gas = ");
  Serial.print(bme.gas_resistance / 1000.0);
  Serial.println(" KOhms");

  Serial.print("Approx. Altitude = ");
  Serial.print(bme.readAltitude(SEALEVELPRESSURE_HPA));
  Serial.println(" m");

  Serial.println();
  delay(2000);
}

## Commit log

2016-02-07 "initial improvemets"
    Added V2, removed overhead to simplufy and made the strick for sensors slip and verticl.
    [EnvironmentOnAStick.brd, EnvironmentOnAStick.sch, EnvironmentOnAStickV2.brd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]
2016-03-29 Added start of V3 for different sensor sets.
    Moved V1/2 into Electron subfolder as they work for Photon and Electron.
    Added BOM for V2, some datasheets and images.
    [BOM.xlsx, EnvironmentOnAStick.brd, EnvironmentOnAStick.sch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]
2016-12-02 Added reverse mount LED to V2 environment stick and moved OSH logo to cover it.
    Exported PCB/schema to pdf and images.
    Added datasheet for BMP180
    [EnvironmentOnAStickV2.brd, EnvironmentOnAStickV2.sch]
2016-12-02 Renamed Environment on a stick to EnvironmentMonitor.
    [EnvironmentMonitorV2.brd, EnvironmentMonitorV2.sch, EnvironmentMonitorV3.brd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]
2016-12-02 Added BME680 to V3 and removed other sensors (except light).
    Added images for V2 and V3 PCBs.
    PCBs sent to DirtyPCB for fab.
    [EnvironmentMonitorV3.brd, EnvironmentMonitorV3.sch]
2016-12-22 Updated identifiers and added BOMs
    [BOM.xlsx, EnvironmentMonitorV2.brd, EnvironmentMonitorV2.sch]
2017-01-04 Fixed validation issues for V2 bom json
2017-05-03 Updated software, added more values onto schematic.
    [EnvironmentMonitorV2.sch]
2017-05-05 Initial version of V4 Environmental monitor with CCS811 and BME280 + 2x light sensors
    [EnvironmentMonitorV4.brd, EnvironmentMonitorV4.sch]
2017-05-05 Minor routing updates to give more space. Ran IDF export (hence extra 113 layer)
    [EnvironmentMonitorV4.brd]
2017-05-07 Added small photon version using SMD photon.
    Sent to DirtyPCBs.
    [EnvironmentMonitorV4.1.brd, EnvironmentMonitorV4.1.sch]
2017-05-22 Work in progress case for the Photon V4.1 PCB
    [PhotonCase-Lid.stl, PhotonCase.scad, PhotonCase.stl]
2017-05-22 Updated library and set part values.
    [EnvironmentMonitorV4.1.brd, EnvironmentMonitorV4.1.sch]
2017-05-31 Update V4.0 PCB to use TEMT6000 rather than the diode which requires amplification, and removed rear sensor.
    Ordered from DirtyPCBs.
    [EnvironmentMonitorV4.brd, EnvironmentMonitorV4.sch]
2018-01-11 Improved visability of names and values.
    [EnvironmentMonitorV4.brd]
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2018-02-17 V1 PCB for Arduino Environment Cap.
    *** DO NOT USE *** - BME680 pins incorrect.
    [ArduinoAirQuailtyTop.brd, ArduinoAirQuailtyTop.sch]
2018-02-17 Updated with light sensor and BME680
    *** DO NOT USE *** BME680 pads flipped.
    [EnvironmentMonitorV3.brd, EnvironmentMonitorV3.sch]
2019-01-12 Version 5 Feather (designed for Particle Argon/Xenon) envionment sensor.
    [EnvironmentMonitorV5.brd, EnvironmentMonitorV5.sch, parts.csv]
2019-01-22 Added V6 to fit Camden Boss CBRS01VWH environment sensor enclosure
    * Added IR Blaster as the enclosure will be on the wall and may be usefull to tx IR.
    * Added GridEye thermal sensor (exerimental) to see if it can be used to detect people.
    * Added Accelerometer to detect tap (case may go over a standard lightswitch cover and be tapped).
    * Added battery (may not fit in enclosure.
    * Added JST for USB power in to allow supply of power via external wiring.
    * Added amplifier for MEMs microphone.
    [EnvironmentMonitorV6.0.brd, EnvironmentMonitorV6.0.sch]
2019-01-22 Version 5.1 - with Mems microphone (note: this has a low signal/noise ratio without an amplifier so may not work well.
    [EnvironmentMonitorV5.1.brd, EnvironmentMonitorV5.1.sch]
2019-01-22 Modified mounting holes to smaller size to match enclosure.
    Modified cutout so it's a larger continious section.
    Updated images from DirtyPCBs
    Added image exports from Eagle.
    Boards updated at DirtyPCBs.
    [EnvironmentMonitorV5.brd, EnvironmentMonitorV6.0.brd, EnvironmentMonitorV6.0.sch]
2019-02-05 Added values and corrected filename for export script
    [EnvironmentMonitorV6.0.brd, EnvironmentMonitorV6.0.sch]
2019-02-21 Work in progress V6.1 with improvements over the Vs board.
    * power for audio amp now via the Xenon to allow for reduced off-power.
    * P-FET for grideye power to allow for lower power shutdown of that
    * accel. int1 to D8 as that's the only pin that allows for wake from deep sleep, so we can use the interval tick on the accel. to wake the CPU if we wish.
    * Added CR2 battery and moved CR123 battery to try and make space for both, although the 123 is to deep for the enclosure.
    * Added ThingySticks Log.
    * Improved placement of the 5V in so it's not by the audio amp and not messing up the ground plane under it.
    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
    [EnvironmentMonitorV6.1.brd, EnvironmentMonitorV6.1.sch]
2020-01-12 First pass back PCB for CamdenBoss environment enclosure with various connectors to try fit and RS485.
    [Environment-V6-RS485-BasePcb.brd, Environment-V6-RS485-BasePcb.sch]
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2020-01-13 First pass mini-environment boards for Arduino Nano 33 and TinyPICO
    [Environment-ArduinoNano44-Mini-Enclosure-V8.brd, Environment-ArduinoNano44-Mini-Enclosure-V8.sch, Environment-TinyPICO-Mini-Enclosure-V9.brd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]
2020-01-16 Arduino Nano 33 Sense with sandwiched CR2032 batteries.
    Work in progress...
    [Environment-ArduinoNano44-Mini-Enclosure-V10.brd, Environment-ArduinoNano44-Mini-Enclosure-V10.sch]
2020-01-17 First pass at front panel for enfironment enclosure.
    [Environment-Front-Panel-V1.brd, Environment-Front-Panel-V1.sch]
2020-01-17 added 7 segment display from LEDs.
    Added batteries as internal layers
    [Environment-ArduinoNano44-Mini-Enclosure-V10.brd, Environment-ArduinoNano44-Mini-Enclosure-V10.sch]
2020-02-24 Split out personal environmental sensor boards into individual Eagle files.
    [Environment-ArduinoNano44-Mini-Enclosure-V10-Bottom.brd, Environment-ArduinoNano44-Mini-Enclosure-V10-Bottom.sch, Environment-ArduinoNano44-Mini-Enclosure-V10-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]
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2020-02-26 Bit of a tidy up to split out the PCBs from the V10 Nano board project into each board needed.
    [Environment-ArduinoNano44-Mini-Enclosure-V10-Bottom.brd, Environment-ArduinoNano44-Mini-Enclosure-V10-Bottom.sch, Environment-ArduinoNano44-Mini-Enclosure-V10-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]
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2020-02-27 Update for V10.1 with improvements...
    * Removed USB C until I get a better foot print for the ones I can buy and replaced with Micro B
    * Reduced cutout in middle layers as it doesn't need so much space.
    * Increased hole size in middle layers for potential NFC wire passthrough to prevent clashes with solder
    * Added potential extra solder connection for bottom to middle layers.
    * Changed bottom boards so they use a top side pad to be soldered to rather than a hole to make the bottom face tidier.
    * Removed switch on the top board as it would have been weird to use
    * Added potential divider for the "3v3" supply to allow monitoring of battery voltage (although this may drain the battery too much)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
    [Environment-ArduinoNano-V10.1-Middle-KeyChain.brd, Environment-ArduinoNano-V10.1-Middle-KeyChain.sch, Environment-ArduinoNano33-V10-CustomBottoms-Arduino.sch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]
2020-02-27 Removing the original all in one design since it's been tidied up and improved on.
    [Environment-ArduinoNano44-Mini-Enclosure-V10.brd, Environment-ArduinoNano44-Mini-Enclosure-V10.sch]
2020-02-28 Added fusion sync.
    Added eagle generated image for top board
    [Environment-ArduinoNano-V10.1-Middle-KeyChain.brd, Environment-ArduinoNano33-V10.1-MiddleBasic.brd, Environment-ArduinoNano44-Mini-Enclosure-V10-Bottom.brd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]
2020-02-28 Improving (fixing!) naming.
    [Environment-ArduinoNano33-V10-Bottom-V10.brd, Environment-ArduinoNano33-V10-Bottom-V10.sch, Environment-ArduinoNano33-V10-Middle-KeyChain.brd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]

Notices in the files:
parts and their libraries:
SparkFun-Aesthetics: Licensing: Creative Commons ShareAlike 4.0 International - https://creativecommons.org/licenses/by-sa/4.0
